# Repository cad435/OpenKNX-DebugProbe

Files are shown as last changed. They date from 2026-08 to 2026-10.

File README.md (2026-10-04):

# OpenKNX DebugProbe

A portable WiFi debugger built on an ESP32-S3 that services an OpenKNX device (RP2040 or
ESP32) through a **single USB-C cable**: **firmware updates** and a **serial console over
TCP**.

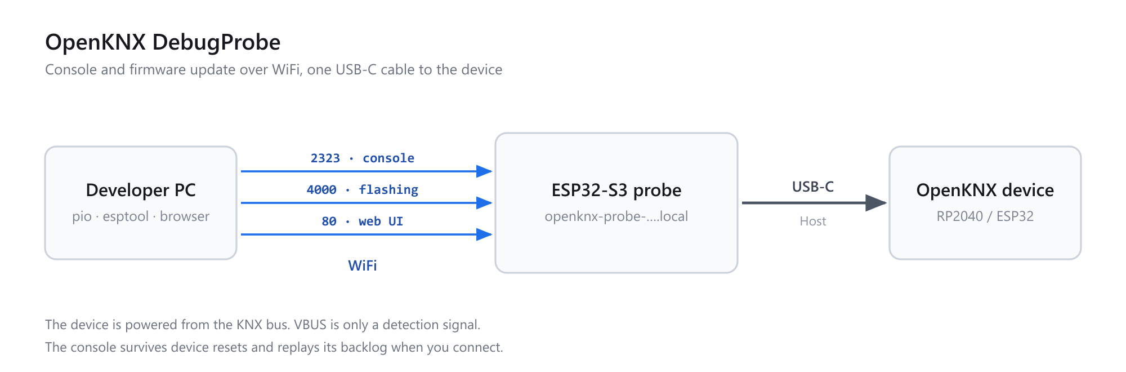
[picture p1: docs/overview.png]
Overview: PC connects to the probe over WiFi, the probe connects to the OpenKNX device with one USB-C cable


## Why

OpenKNX REG1 devices live inside a distribution cabinet. Until now, a firmware update or a
look at the debug console meant carrying a laptop to the cabinet. The probe stays plugged
into the device and is reached over WiFi.

It is built specifically for OpenKNX devices but is **not part of the OpenKNX project** — a
private tool, for now with no affiliation to the OpenKNX group.

## Status

**Working and verified on real hardware.** The whole development cycle runs over WiFi:

| | |
|---|---|
| WiFi setup | captive portal, 3 connection attempts, then a fallback AP |
| Self-update | HTTP OTA with A/B slots and automatic rollback |
| Target detection | RP2040, ESP32, CH32V003, CH34x/CP210x/FTDI — including serial number |
| Console | `socket://…:2323` with a 16 KB backlog, survives target resets |
| Control lines | `rfc2217://…:4000` with baud rate and DTR/RTS |
| Firmware to the target | UF2 over HTTP, fully validated, then written over USB MSC |
| Getting into BOOTSEL | 1200-baud touch, issued by the probe itself — no button press |
| Commands to the target | input line in the browser, selectable line ending, history with ↑/↓ |
| Power saving | the radio dozes while no client is attached to 2323 or 4000 |
| Console in the browser | follow along without a terminal; prompt and ANSI are resolved |
| Ready-made configuration | the `platformio.ini` lines as a copy field and via `/api/snippet` |
| Restarting the target | `/api/reset` and `/api/bootmode`, two buttons in the UI — the probe decides what a given target actually supports and says so |
| Firmware to a CH32V003 | `/api/ch32/flash`, over the rv003usb bootloader's own protocol — no minichlink on the PC |
| Web UI outside the image | in a LittleFS partition, replaceable over WiFi with `/api/fs` |
| Why the probe last started | `reset_reason` tells a brownout from a crash — a target with a high inrush can reset the probe |
| Cell voltage | measured through a divider on the adapter board, reported as `battery` in `/api/status` |

Architecture, hardware and interfaces in detail: **[docs/](docs/)**.

## Modes of operation

- **Normal operation:** `usb_host_cdc_acm` reads the target's console, a TCP server on port
  2323 forwards it to the PC.
- **Flashing:** 1200-baud touch → target reboots into BOOTSEL → `usb_host_msc` writes the
  UF2 as raw 512-byte sectors → reset. `POST /api/flash` issues the touch itself, **after**
  the UF2 has been fully validated; nobody has to press a button on the device. If the mass
  storage device does not appear, one retry follows, then a `409` with a reason — and the
  console is put back to 115200 with DTR/RTS at their idle levels.

The radio saves power when nobody is listening: while a client is attached to 2323 or 4000
it runs with `WIFI_PS_NONE`, otherwise it dozes in `MIN_MODEM`. The console livestream and
flashing are demonstrably unaffected, while the ESP32-S3 runs noticeably cooler when idle.
Only an accepted TCP client gets a vote: HTTP, the web UI and API calls do **not** keep the
radio awake. So an open browser tab costs nothing, a forgotten `pio device monitor` does.
The current state is reported as `radio_awake` in `/api/status` and as the "Funk" row in the
web UI.

The web UI does not only follow the console, it also has a line for **sending commands** to
the target. The line ending is selectable (CR, LF, CRLF, none), because the OpenKNX console
works character by character while other firmware waits for a complete line. ↑/↓ steps
through recently sent commands.

## Supported targets and their USB IDs

**Read the caveat before the table.** On targets with native USB, the VID:PID of the
*running application* is chosen by its firmware, not by the chip. The values below are the
common defaults, not a guarantee. Only the **bootloader** IDs are fixed — they live in the
boot ROM or in a bootloader that is flashed once and then left alone.

That asymmetry is why the probe identifies bootloaders by VID:PID and applications by their
USB class: the first is reliable, the second is not.

| Target | Application (typical) | Bootloader / download | How the probe gets there |
|---|---|---|---|
| RP2040 (arduino-pico) | `2E8A:00C0` | `2E8A:0003` RPI-RP2, mass storage | 1200-baud touch |
| RP2040 (pico-sdk) | `2E8A:000A`, `2E8A:0009` | `2E8A:0003` | 1200-baud touch |
| ESP32-S3 / -C3, native USB | `303A:1001` | **same IDs** — the ROM uses the same USB-Serial-JTAG | DTR/RTS sequence with boot latch |
| ESP32-S2, native USB | `303A:0002`, `303A:1000` | `303A:0002` | DTR/RTS sequence |
| Any board behind a UART bridge | the bridge chip, see below | **unchanged** — the bridge stays visible either way | DTR/RTS on IO0 and EN |
| CH32V003 with rv003usb | firmware's choice (`1209:D003` in the example) | `1209:B003` | HID feature report `0xAB` |

UART bridges, for completeness — these never change between application and bootloader,
because the mode is selected with DTR/RTS rather than by re-enumerating:

`1A86:7523` CH340 · `1A86:5523` CH341 · `1A86:55D3` CH343 · `1A86:55D4` CH9102 ·
`10C4:EA60` CP2102 · `10C4:EA70` CP2105 · `10C4:EA71` CP2108 · `0403:6001` FT232R ·
`0403:6010` FT2232 · `0403:6014` FT232H · `0403:6015` FT230X · `067B:2303` PL2303

### What the probe can do with each

**✅ means verified on real hardware**, not merely implemented. Where a row says
*untested*, the code is there and follows the reference implementation — but nothing has
confirmed it yet, and this table would be worth little if it blurred that line.

| Target | Console | Flash | Restart into the application | Into the bootloader |
|---|---|---|---|---|
| RP2040 (Pico) | ✅ | ✅ UF2 over `/api/flash` | ✅ PICOBOOT, from BOOTSEL only | ✅ 1200-baud touch |
| ESP32-S3 / -C3, native USB | ✅ | ✅ esptool over RFC2217 | ✅ RTS pulse | ✅ DTR/RTS with boot latch |
| CH32V003 (rv003usb bootloader) | — | ✅ `/api/ch32/flash` | ✅ starts the application | ✅ HID feature report `0xAB` |
| ESP32 behind a UART bridge | ✅ | esptool over RFC2217 | *untested* | *untested* |
| Any other HID device | — | — | — | the `0xAB` attempt; a stall is reported as a refusal |

**A running RP2040 cannot be reset over the cable.** Native USB has no reset line, and
PICOBOOT lives only in the boot ROM. Bootmode followed by reset gets there anyway — through
the boot ROM, two clicks, no cable.

**The CH32V003 flasher is written for the V003 specifically.** Sector size and the flash
controller addresses are fixed in the code. Chip *detection* also knows V002/004/005/006/007
and X033, but flashing them is not claimed — a different sector size would have to be taught
first. The scratchpad negotiation and the choice of boot routine already handle the larger
bootloaders, so that part is done.

## Status LED

The module's RGB LED (WS2812 on GPIO48) shows the operating state. Highest urgency wins —
`flashing` beats everything, because pulling the cable there does real damage.

| State | LED | Trigger |
|---|---|---|
| `flashing` | orange, blinking at 320 ms | `POST /api/flash` is writing — **do not unplug** |
| `battery_low` | red, blinking at 1 s | cell nearly empty |
| `no_wifi` | red, pulsing | not connected to WiFi, including portal mode |
| `busy` | solid yellow | a client is attached to 2323 or 4000 |
| `target_ready` | solid green | a target is detected |
| `idle` | green, pulsing | ready, no target attached |

The current mode is reported as `led.mode` in `/api/status`.

Brightness is capped well below maximum. A WS2812 at full white draws around 60 mA, which
matters on battery.

Two more LEDs sit on the SuperMini:

| LED | Meaning |
|---|---|
| blue | the Li-ion charger: on while charging, off once the cell is full, blinking when no cell is connected. |
| red | **shares GPIO48 with the RGB LED.** It lights while the pin is left alone and stays dark as soon as the firmware drives the WS2812 — so on this firmware it is permanently off. |

The shared pin was confirmed on hardware: moving the status LED to another pin brings the
red one back, moving it to GPIO48 turns it off again. It is therefore not a power indicator,
and the RGB LED costs you the red one. If you would rather keep the red LED, point the
status LED at a free pin with `POST /api/led?gpio=N` — the value is stored in NVS.

## Battery

On the adapter board a 1M/1M divider sits behind the battery switch and feeds GPIO5
(ADC1). `/api/status` reports it, and the UI shows a "Zelle" row:

```json
"battery": { "available": true, "level": "normal", "settled": true,
             "mv": 3910, "pin_mv": 1955, "percent": 67, "trim": 1000 }
```

| Field | Meaning |
|---|---|
| `level` | `absent`, `normal`, `low` (< 3.55 V), `critical` (< 3.30 V), or `unknown` while warming up |
| `settled` | false for the first ~25 s after boot, see below |
| `mv` / `pin_mv` | cell voltage and the raw voltage at the divider tap — if the two disagree by anything other than the factor of two, the divider is not what you think it is |
| `percent` | a rough gauge, not a measurement: a generic Li-ion curve over 13 support points, linearly interpolated, with no load compensation — at 30-120 mA the cell sits well below 0.1 C, so the IR drop is small against the spread of the curve itself. It reads 0 % at 3.30 V, the same point as `critical`, because the module's LDO gives up somewhere between 3.0 and 3.5 V; capacity below that is not usable here |

Two things worth knowing:

- **`absent` is the normal case on USB.** The divider is behind the battery switch, so
  with the switch off — or no cell at all — the tap sits at ground. That is not a fault.
- **The first ~25 s after boot report `unknown`.** The tap carries 10 µF against a 500 kΩ
  source impedance, so it charges with a 5 s time constant and reads low until it has
  settled. Without that hold-off the probe would announce an empty cell at every start.

If the reading disagrees with a multimeter, trim it once: measure at the cell and post
the value.

```bash
curl -X POST "http://openknx-probe-xxxx.local/api/battery/calibrate?mv=3870"
```

The factor is stored in NVS and applied from then on. 1 % resistors alone allow 2 % on the
divider ratio, and the ADC characteristic adds to that — around 100 mV at 3.8 V, enough to
move the low-battery warning by half an hour. Corrections beyond 25 % are rejected.

## Enclosure

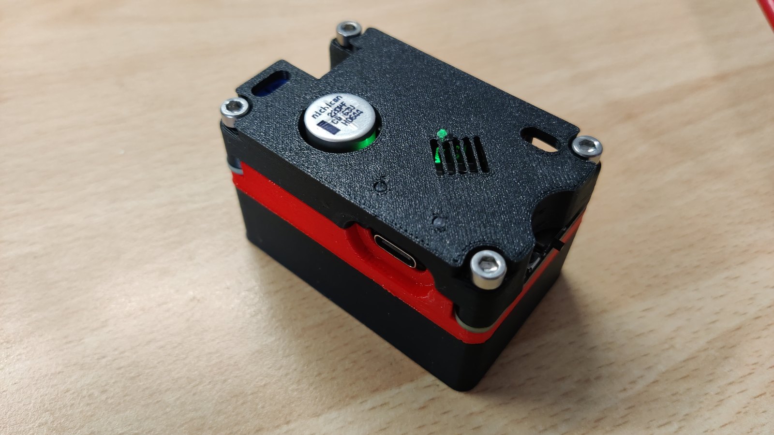
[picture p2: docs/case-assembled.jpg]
The assembled probe in its printed enclosure: black lid, red body, black battery compartment, four socket-head screws in the corners


A printable enclosure is included as a Fusion 360 archive:
[`hardware/OpenKNXDebugProbe.f3z`](hardware/OpenKNXDebugProbe.f3z). It is made of three
parts:

| Part | Purpose |
|---|---|
| **Top** | lid with the openings for USB-C, the status LED and the electrolytic capacitor |
| **Bottom** | the counterpart; the PCB is clamped between top and bottom |
| **Battery compartment** | optional, goes underneath and holds the cell |

Assembly needs **four M3×20 screws**. They go in from the top and thread straight into the
plastic — no heat-set inserts, no captive nuts. The board is not screwed down itself; it is
held by being clamped between the top and bottom parts.

**Without a battery** you can leave the battery compartment off and counter the four screws
with M3 nuts underneath instead.

## PlatformIO integration

No extra hardware is needed on the PC side — a few lines in the target project's
`platformio.ini` are enough. The probe hands them out itself, since it knows its own name
and what is plugged in:

```powershell
curl.exe http://openknx-probe-xxxx.local/api/snippet
```

The web UI shows the same lines in two copy fields as soon as a target is detected. If you
would rather write them yourself:

```ini
; RP2040 target (UF2 over HTTP)
monitor_port    = socket://openknx-probe-xxxx.local:2323
upload_protocol = custom
upload_command  = curl --fail-with-body --data-binary "@$BUILD_DIR/${PROGNAME}.uf2" http://openknx-probe-xxxx.local/api/flash

; ESP32 target (esptool over RFC2217)
upload_port     = rfc2217://openknx-probe-xxxx.local:4000
upload_speed    = 460800
```

Fully commented in [tools/platformio-snippet.ini](tools/platformio-snippet.ini).

## Build and flash

```powershell
cd firmware
pio run              # build
pio run -t upload    # flash (the port is detected automatically)
```

PlatformIO with `framework = espidf`, platform espressif32 54.3.21 (ESP-IDF 5.4.2). A
separate ESP-IDF installation is not required.

## First-time setup

1. Flash the firmware. The probe finds no credentials and opens an open WiFi network
   named after itself, e.g. `OpenKNX-Probe-A1B2`.
2. Connect to it — the captive portal opens by itself, otherwise `http://192.168.4.1/`.
3. Pick a network and enter the password. The device name is not configurable: it is
   always `OpenKNX-Probe-<last two MAC bytes>`, so it is unique per board and matches
   the setup network you just joined.
4. After the restart the probe is reachable at `http://<name>.local/`.

The probe remembers **one** network. Entering another one replaces it. Also note that the
fallback AP only ever opens during startup: once the probe has an address, a link that
gets weak or drops is retried indefinitely and never falls back to the portal. To reach
the portal on purpose, restart the probe while its network is out of reach.

## Self-update

From the browser via the start page, or:

```powershell
curl.exe --fail-with-body --data-binary "@firmware/.pio/build/probe/firmware.bin" `
         http://openknx-probe-xxxx.local/api/update
```

A foreign or damaged image is rejected with HTTP 400 before anything is written. If a new
image does not boot cleanly, the bootloader falls back to the previous one automatically.

## Security

The probe has **no authentication**. Anyone who can reach it on the network can, with no
further hurdle,

- write firmware into the attached target (`POST /api/flash`),
- overwrite the probe itself over OTA (`POST /api/update`),
- send commands to the target's console (`POST /api/console`),
- push the target into BOOTSEL (`POST /api/bootsel`), and
- erase the stored WiFi credentials (`POST /api/wifi/forget`).

The setup AP is **open** as well, without WPA — during first-time setup anyone within radio
range can set the credentials.

This is deliberate: the probe is a tool for the bench and your own development network,
where turnaround time matters and a login on every flash would only get in the way. But it
follows where it does **not** belong: not on a guest network, not on a network with
strangers on it, and never behind a port forward or a reverse proxy exposed to the
internet. If it stays in the cabinet permanently, it belongs on the same trusted network as
the devices it is allowed to flash — because that is exactly what anyone who reaches it can
do.

## Documentation

| File | Contents |
|---|---|
| [docs/architecture.md](docs/architecture.md) | state machine, tasks, core split |
| [hardware/](hardware/) | probe module, power supply, battery, VBUS |
| [docs/protocol.md](docs/protocol.md) | HTTP API and TCP serial interface |

`docs/architecture.md` is currently German only.

## License

[GNU General Public License v3.0 or later](LICENSE) (`GPL-3.0-or-later`).

Espressif's USB host and mDNS components, which the build pulls in through the Component
Manager, are Apache-2.0 licensed and are not part of this repository.

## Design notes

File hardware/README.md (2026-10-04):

# Hardware

Schematic as PDF: [OpenKNX-DebugProbe_V0.2-Schematic.PDF](OpenKNX-DebugProbe_V0.2-Schematic.PDF)

Printable enclosure: [OpenKNXDebugProbe.f3z](OpenKNXDebugProbe.f3z) (Fusion 360 archive).
Three parts, four M3×20 screws — see [Enclosure](../README.md#enclosure) in the main README.

## Probe module

The controller is an **ESP32-S3 SuperMini** (FH4R2 variant) — **not an ESP32-S3 Zero!**
The USB-C connector towards the target is the module's own — there is none on the adapter board.

The module's 4 MB of flash are the tightest constraint: two OTA slots of 1.875 MB each,
leaving no room for a UF2 staging partition. The target's UF2 is therefore buffered in
PSRAM.

## Power supply

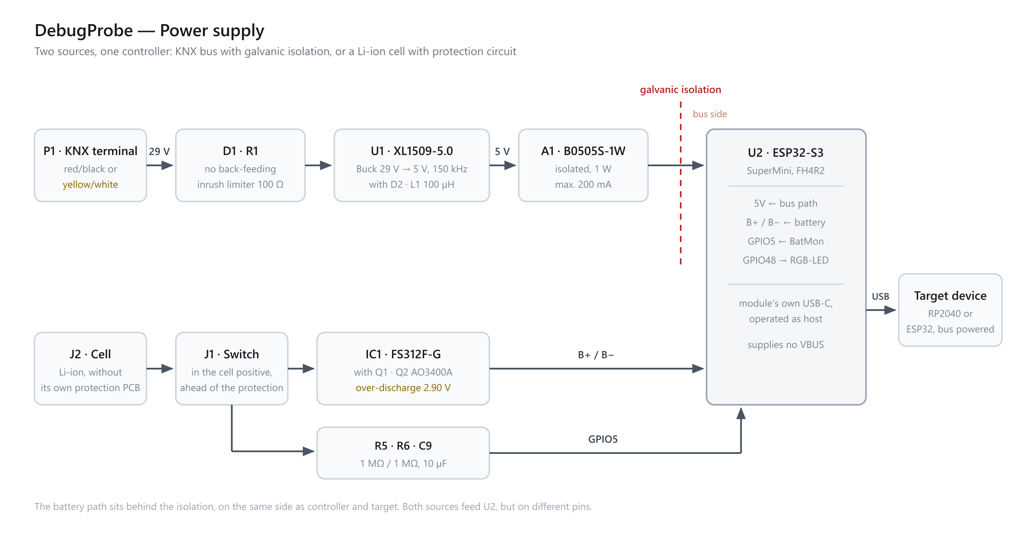
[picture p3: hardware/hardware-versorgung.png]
Power supply


`D1` sits directly behind KNX+ and prevents back-feeding: KNX transmits by briefly pulling
the bus LOW, and no charge may flow back into the bus from the input capacitor. That is the
reason for it — not reverse-polarity protection.

`A1` breaks the ground loop between the bus supply and the target — either the red/black or
the yellow/white terminal pair can be used, or any other supply from 5 V to 30 V.

## Battery (optional)

The battery is optional; without it the probe runs from the bus supply. Charging is handled
by the ESP32-S3 SuperMini's charger. The protection circuit against over-discharge, however,
sits on this probe board, because the cell does not bring its own.

**Open the switch when the probe is not in use.** It disconnects the cell completely, so
that neither the module nor the protection circuit draws current.

The cell voltage reaches an ADC input through a divider. Its 10 µF give a time constant of
5 s — so the first usable reading is about 30 s after switch-on.

## VBUS

All OpenKNX devices are KNX bus powered. **The probe supplies no VBUS**, and an RP2040/ESP32
target with native USB still enumerates: it asserts its D+ pull-up as soon as the board has
power.

On the bench it is different — a bare RP2040 devkit is USB powered and draws real current
from VBUS.

## Proof-of-Concept prototype

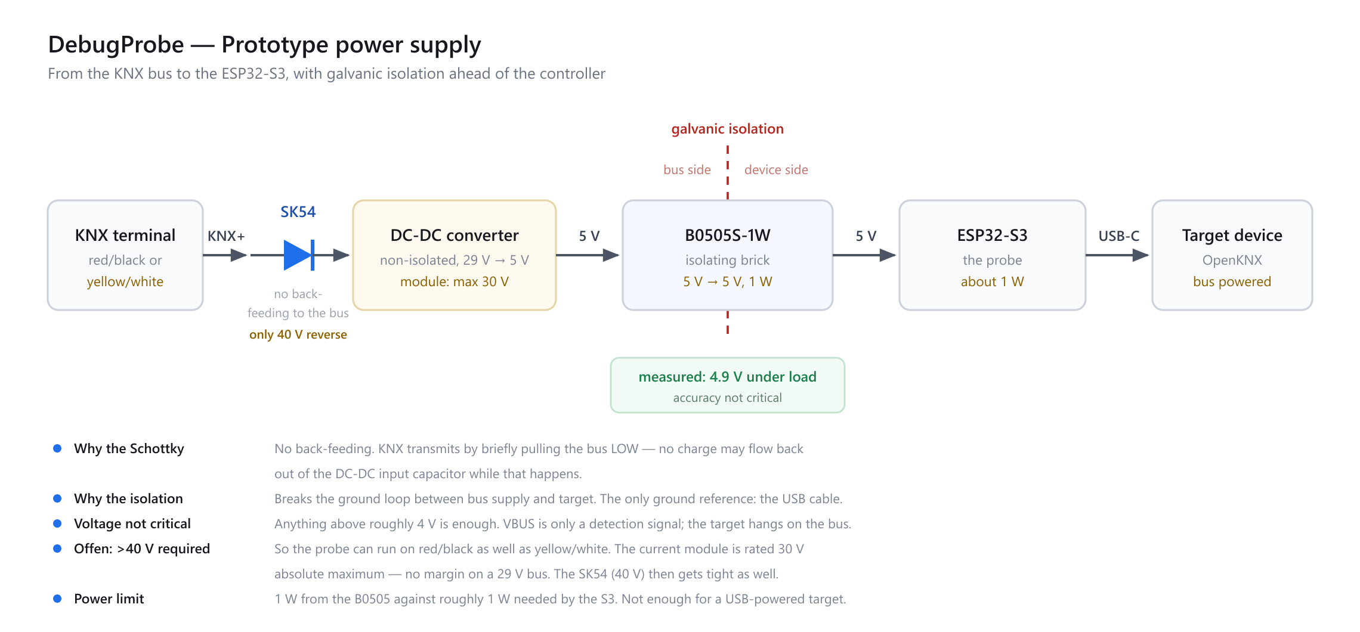
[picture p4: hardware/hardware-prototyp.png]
Power supply chain of the prototype


The prototype differs from the schematic: an **MP1584** module serves as the buck converter
instead of `U1`, and the battery branch is missing. The isolated converter and the
controller are the same.

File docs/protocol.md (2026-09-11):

# Interfaces

Legend: **[live]** = implemented and verified on real hardware.

For uploads the file content is always transferred as the **raw request body**
(`--data-binary`), never as multipart. That saves a multipart parser on the probe and works
equally well from a browser (`fetch(url, {method:"POST", body: file})`) and from `curl`.

## Discovery

mDNS hostname from the portal, default `openknx-probe-<mac>` (e.g.
`openknx-probe-xxxx.local`). Service `_http._tcp`, instance name
"OpenKNX DebugProbe". **[live]**

## TCP — the target's serial console **[live]**

| Port | Protocol | Used for |
|---|---|---|
| 2323 | raw, transparent | monitor, terminal |
| 4000 | RFC2217 (Telnet + COM-PORT-OPTION) | anything needing baud rate and DTR/RTS |

Both share the same 16 KB backlog and may be connected at the same time.

Behaviour on **2323**:

- On connect you first get a status line `[probe] …`, then the backlog — including the boot
  messages that appeared before you connected.
- If the target disappears (reset or flash), **the TCP connection stays up**; the state
  change appears as a `[probe]` line in the stream.
- One client at a time.

Behaviour on **4000**:

- Starts at the current end of the buffer, not at its beginning — a flashing tool should not
  find old console output in its protocol stream.
- Supported subnegotiations: `SET_BAUDRATE`, `SET_DATASIZE`, `SET_PARITY`, `SET_STOPSIZE`,
  `SET_CONTROL` (DTR/RTS), `SET_LINESTATE_MASK`, `SET_MODEMSTATE_MASK`, `PURGE_DATA`. BREAK
  is not passed through yet.
- 0xFF in the payload stream is doubled in both directions.

PC side:

```
monitor_port = socket://openknx-probe-xxxx.local:2323
esptool --port rfc2217://openknx-probe-xxxx.local:4000 write_flash ...
```

## HTTP API

### `GET /` **[live]**

Status and update page. In portal mode the provisioning form instead.

### `GET /api/status` **[live]**

```json
{
  "name": "openknx-probe-xxxx",
  "version": "1",
  "build": "Aug 19 2026 00:23:28",
  "partition": "ota_1",
  "pending_verify": false,
  "wifi": "connected",
  "ssid": "<SSID>",
  "rssi": -43,
  "ip": "<IP>",
  "uptime_s": 47,
  "heap_free": 2230844,
  "target":  { "state": "connected", "description": "…", "vid": "0x2E8A", … },
  "console": { "port": 2323, "client": "…", "rx": 12345, "rfc2217_port": 4000, … },
  "snippet": { "comment": "…", "monitor": "…", "upload": "…" }
}
```

`wifi`: `idle` | `connecting` | `connected` | `portal`
`pending_verify`: `true` while a freshly flashed image is still on probation.
`target` and `console` are absent while the USB host has not been started; the fields inside
`target` only exist in state `connected`.

Four fields inside `target` are the exception — they exist in every state, because the web UI
needs them to decide whether the restart buttons do anything at all:

| field | meaning |
|---|---|
| `can_reset` | a restart into the target's own application is possible |
| `reset_how` | the method used, or — when `can_reset` is `false` — the reason |
| `can_bootmode` | the target can be halted in its bootloader |
| `bootmode_how` | same, for the bootloader |

Both `*_how` fields are plain German text meant to be shown to a human. Do not parse them;
they are documentation, not a protocol.

One call is enough for the whole web UI page — it polls this single route.

### `POST /api/update` **[live]** — firmware of the **probe**

Raw body with the ESP32 application image. Writes into the inactive OTA slot and reboots
afterwards.

```powershell
curl.exe --fail-with-body --data-binary "@firmware/.pio/build/probe/firmware.bin" http://…/api/update
```

| Status | Meaning |
|---|---|
| 200 | written, reboot follows (`{"status":"ok","partition":"ota_1"}`) |
| 400 | not a valid ESP32 image, wrong project, or bad checksum — **nothing was written** |
| 409 | an update is already running |
| 413 | image larger than the OTA slot |

Checked before the first write: image magic `0xE9`, a present `esp_app_desc_t`, and a
matching project name. In particular this keeps a UF2 that was actually meant for the target
from ending up in the ESP32 by accident.

### `POST /api/fs` **[live]** — the web UI (filesystem image)

Writes the LittleFS image into the `storage` partition. The counterpart of `/api/update`:
that one carries the firmware, this one the interface. Body is the raw `littlefs.bin`.

```
curl.exe --fail-with-body --data-binary "@firmware/.pio/build/probe/littlefs.bin" http://openknx-probe-xxxx.local/api/fs
```

```json
{"status":"ok","written":196608,"total_kb":180,"used_kb":28,"index":true}
```

`index` is `false` when the image contains no `index.html` — the upload worked, but the probe
will still serve the built-in emergency page.

| code | meaning |
|---|---|
| 400 | empty body, too short, or not a LittleFS image |
| 409 | an upload is already running |
| 413 | image larger than the partition |
| 500 | erase, write, or remount failed |

**Why this endpoint exists at all.** Without it, every change to the interface needs a serial
`pio run -t uploadfs`. On a probe whose USB-C port is occupied by the target under test, that
means unplugging cables — the exact thing this project exists to abolish.

**The image is validated before anything is erased.** LittleFS carries the string `littlefs`
at offset 8 of its first block; that is checked the same way `/api/update` checks the ESP32
image magic. A `firmware.bin` sent here is refused rather than silently turned into an empty
interface.

**An aborted upload is not fatal.** The filesystem is unmounted for the duration, so a broken
transfer leaves the partition incomplete — the probe keeps running, serves the emergency page,
and this endpoint stays reachable. A second attempt repairs it. What cannot be repaired this
way is a probe that no longer joins the network; that is what the serial path is for.

### `GET /api/scan` **[live]**

List of visible WiFi networks, sortable by signal strength:
`[{"ssid":"…","rssi":-43,"open":false}, …]` (max. 20 entries).

### `POST /api/wifi/connect` **[live]**

`application/x-www-form-urlencoded` with `ssid`, `pass`, optionally `name` (device name).
Stores to NVS and reboots. Used by the captive portal.

### `POST /api/wifi/forget` **[live]**

Erases the stored credentials and reboots into the portal.

---

### `POST /api/flash` **[live]** — firmware of the **target**

Raw body with the UF2. It is buffered in PSRAM, **fully validated**, and only then written
as raw 512-byte sectors. Magics, the block chain, `numBlocks` and the family ID are checked;
if anything fails, not a single sector reaches the target.

If the target is still running its application, the endpoint pushes it into BOOTSEL
**itself** with a 1200-baud touch — only after validation, so a broken file cannot tear the
target out of its application. Nobody has to press a button. If the target already sits in
BOOTSEL, nothing is touched.

```powershell
curl.exe --fail-with-body --data-binary "@firmware.uf2" http://openknx-probe-xxxx.local/api/flash
```

| Status | Meaning |
|---|---|
| 200 | written (`{"blocks":…,"written":…}`), the target reboots |
| 400 | invalid UF2 — **nothing** on the target was changed |
| 409 | touch attempted, but BOOTSEL not reached (reason in `error`) |
| 413 | no memory for the file |
| 502 | write error midway through |

Every rejection names its reason in `{"error":…}`. Checks run in the order in which the
causes actually occur: **the magic at the start of the file first**, only then the size. The
other way round, the most common case — an accidentally sent `firmware.bin` — would get
"not a multiple of 512", and that points in the wrong direction.

```json
{"error":"kein UF2-Magic (0x0A324655) am Dateianfang, sondern 0x20003FFC, 572636 Byte
          empfangen - das sieht nach einer .bin aus. In der platformio.ini
          \"@$BUILD_DIR/${PROGNAME}.uf2\" statt \"@$SOURCE\" verwenden."}
```

The probe decides this after the first 512 bytes, **before** it requests memory for the
file. For the text to also show up in the PlatformIO log, the snippet needs
`--fail-with-body` instead of `-f`: with `-f`, curl swallows the body and all that remains
is `curl: (22)`.

`?validate_only=1` checks the file without writing and returns
`{"blocks":…,"payload_bytes":…,"first_address":…,"family":…,"status":"valid"}`.

The endpoint establishes BOOTSEL mode itself (1200-baud touch, see above) — **as long as the
target's firmware still enumerates**. Only when it no longer does, somebody has to step in:
BOOTSEL and RUN are accessible from the front panel, and the probe detects the state change
by itself. A power cycle over VBUS explicitly does not help there, because all OpenKNX
devices are KNX bus powered — see [hardware/](../hardware/).

### `GET /api/console?cursor=N` **[live]**

The target console's backlog for the browser. `cursor` is an **absolute** position in the
stream, not a ring-buffer index; without the parameter you get the entire available buffer.

```json
{ "cursor": 20480, "skipped": 0, "more": false, "data": "…" }
```

| Field | Meaning |
|---|---|
| `cursor` | use this value for the next request |
| `skipped` | this many bytes were overwritten before they were fetched |
| `more` | there is more waiting — fetch again immediately, without waiting |
| `data` | the raw bytes, JSON-escaped (control characters as `\u00XX`) |

At most 4 KB per response, so that a single response burdens neither the heap nor the
browser; hence the `more` flag.

The raw bytes stay raw: CR, LF and ANSI sequences pass through unchanged. The OpenKNX
console rewrites its prompt after every log line and erases it next time with `ESC[2K` — the
web UI runs a small line state machine for that (CR only moves the cursor, it erases
nothing).

`/api/status` carries `radio_awake` alongside: `true` while a client is attached to 2323 or
4000 and the radio therefore runs with `WIFI_PS_NONE`, otherwise `false`
(`WIFI_PS_MIN_MODEM`). HTTP itself does **not** keep the radio awake.

### `POST /api/console` **[live]** — command to the target

The body is the raw text **without** a line ending; `?eol=cr|lf|crlf|none` decides what gets
appended (default `cr`). Response `{"status":"sent","bytes":N}`.

Why it is selectable: the OpenKNX console works character by character — every keystroke is
processed and echoed immediately — while other firmware waits for a complete line. A
hard-coded line ending would break one case in order to serve the other. An empty body with
`eol=cr` sends just the line ending, which makes the prompt redraw.

The bytes take the same path as those of a TCP client on port 2323, so they are counted in
`bytesToTarget()` and appear in `/api/status` under `console.tx`. Anything longer than
512 bytes is rejected with `413` — this endpoint is for typed commands, not for files.

| Status | Meaning |
|---|---|
| 200 | written |
| 400 | unknown `eol`, or nothing to send |
| 409 | no serial session to the target is open |
| 413 | command longer than 512 bytes |
| 502 | writing to the target failed |

Verified on hardware against an OpenKNX fan actuator: `h` returns the complete help,
`uptime` the running time — both entered through the web console.

### `POST /api/reset` **[live]** — restart the target

Restarts the attached target into its own application. No body.

```json
{"status":"reset","method":"RTS-Puls auf EN (esptool-Hard-Reset)","msc_ready":false}
```

`method` names what the probe actually did, which differs per target — there is no single
mechanism that restarts every device over USB:

| target | reset into the application |
|---|---|
| UART bridge (CH34x / CP210x / FTDI) | RTS pulse on EN, the esptool hard reset |
| Espressif with native USB | RTS pulse through the USB-Serial-JTAG, after clearing the boot latch |
| RP2040 (CDC) | **not directly** — but bootmode followed by reset gets there via the boot ROM |
| RP2040 in BOOTSEL | PICOBOOT reboot over the boot ROM's vendor interface |

**A running RP2040 with native USB cannot be reset directly.** DTR and RTS end up in the
target's firmware, not at its RUN pin, and there is no line in between. The endpoint says so
instead of pretending: `409` with the reason in `error`. Ask `/api/status` beforehand —
`can_reset` carries the same answer without touching anything.

**It still works remotely, in two steps:** `POST /api/bootmode`, then `POST /api/reset`. The
first uses the 1200-baud touch, the second the boot ROM's PICOBOOT interface — the same one
`picotool reboot` drives. The route goes through the boot ROM, but it needs no cable. Once a
target sits in BOOTSEL, `/api/status` reports `picoboot: true` and `can_reset: true`.

### `POST /api/bootmode` **[live]** — halt the target in its bootloader

The counterpart. No body.

```json
{"status":"bootmode","method":"1200-Baud-Touch","msc_ready":true,"msc_kb":131071}
```

| target | into the bootloader |
|---|---|
| UART bridge | DTR/RTS sequence on IO0 and EN, the esptool bootloader reset |
| Espressif with native USB | DTR/RTS sequence through the USB-Serial-JTAG, setting the boot latch |
| RP2040 (CDC) | 1200-baud touch — the same thing `/api/flash` does internally |
| RP2040 in BOOTSEL | nothing to do, `method` says so |

Useful for testing the touch without overwriting the target's firmware, and as a button in
the web UI. On failure, `409` with the same `error` text as `/api/flash`.

An RP2040 returns to its application through a reset (RUN button or power cycle) or through
the next `POST /api/flash`. The flash contents are untouched by the touch.

**Both control-line sequences set DTR and RTS in a single USB control transfer.** The
intermediate state that pyserial produces over RFC2217 — one line at a time, roughly 50 ms
apart — never occurs here. That state is exactly what the auto-reset circuit on ESP32 boards
is built to ignore.

**On chips with a native USB-Serial-JTAG the same interlock lives inside the chip**, which
is why download mode is not selected by a pin level but by a latch: a phase with DTR
asserted is remembered, and the next reset then boots into download mode. The probe clears
that latch before a plain restart and sets it before a bootloader entry. Verified on an
ESP32-S3: `/api/reset` yields `boot:0x2b (SPI_FAST_FLASH_BOOT)`, `/api/bootmode` yields
`boot:0x23 (DOWNLOAD(USB/UART0))`.

### `POST /api/bootsel` **[live]** — deprecated alias

The old name of `/api/bootmode`, from when the only supported target was an RP2040. Same
handler, same response — including `status:"bootmode"`. New code should use `/api/bootmode`.

### `GET /api/snippet` **[live]**

The ready-made `platformio.ini` lines for the currently attached target, as `text/plain`.
Meant for scripts and AI agents: one call is enough to get the right configuration without
knowing the ports and baud rates yourself.

```
; OpenKNX DebugProbe - openknx-probe-xxxx.local
; Ziel: Raspberry Pi Pico (USB-CDC) (2E8A:000A)
monitor_port  = socket://openknx-probe-xxxx.local:2323
monitor_speed = 115200
upload_protocol = custom
upload_command  = curl --fail-with-body --data-binary "@$BUILD_DIR/${PROGNAME}.uf2" http://openknx-probe-xxxx.local/api/flash
```

Which upload path appears depends on the detected target: **VID `0x2E8A`** (RP2040) gets the
UF2 path over `/api/flash`, everything else `upload_port = rfc2217://…:4000` with
`upload_speed = 460800`. With no target attached only the two console lines remain, with
`; Ziel: kein Zielgeraet angesteckt` as the comment.

The same strings appear under `snippet` in `/api/status` and fill the two copy fields in the
web UI. They are built **in the firmware** (`buildSnippet()` in `main.cpp`) — that way the
endpoint and the display cannot drift apart when a port changes.

## PlatformIO integration in the target project **[live]**

```ini
[env:openknx_remote]
monitor_port    = socket://openknx-probe-xxxx.local:2323
upload_protocol = custom
upload_command  = curl --fail-with-body --data-binary "@$BUILD_DIR/${PROGNAME}.uf2" http://openknx-probe-xxxx.local/api/flash
```

Fully commented in `tools/platformio-snippet.ini`, which also has the `rfc2217://` variant
for ESP32 targets.

More convenient than copying it by hand is fetching both — the probe knows its own name and
the attached target:

```powershell
curl.exe http://openknx-probe-xxxx.local/api/snippet
```

The web UI shows the same lines in two copy fields.

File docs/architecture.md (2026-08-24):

# Architektur

## Überblick

```
   PC                          WLAN                    Schaltschrank
+---------+                                   +-------------------------+
| pio     |--- TCP  :2323 ------------------->| serial_bridge           |
| monitor |                                   |        ^                |
|         |                                   |        v                |
| curl /  |--- HTTP :80  ------------------->| web_api -> uf2_flasher  |
| Browser |                                   |        ^                |
+---------+                                   |        v                |
                                              | usb_target (USB Host)   |
                                              | target_power (VBUS)     |
                                              +-----------+-------------+
                                                          | USB-C
                                                          v
                                                 OpenKNX RP2040
```

## Task- und Core-Aufteilung

| Task | Core | Aufgabe |
|---|---|---|
| `usb_host_lib` (IDF) | 1 | USB-Host-Eventschleife, muss möglichst jitterarm laufen |
| `usb_target` | 1 | Zustandsmaschine, CDC-Transfers, MSC-Transfers |
| `serial_bridge` | 0 | TCP-Server, Ringpuffer |
| `web_api` (httpd) | 0 | HTTP-Server, Upload-Streaming |
| WiFi/lwIP (IDF) | 0 | Funk |

Die strikte Trennung USB (Core 1) / Netz (Core 0) ist der Hauptgrund für den ESP32-S3:
auf einem Einkern-S2 konkurrieren USB-Host-Stack und WiFi um dieselbe CPU, und genau das
erzeugt sporadische Aussetzer, die sich später kaum reproduzieren lassen.

## Zustandsmaschine `usb_target`

```
        +-----------------+
        |  NO_TARGET      |  kein Gerät / VBUS aus
        +--------+--------+
                 | Device connect
                 v
        +-----------------+
        |  ENUMERATING    |
        +--+-----------+--+
           |           |
   CDC-ACM |           | MSC (VID 2e8a / PID 0003)
           v           v
   +-------------+  +-------------+
   |  CONSOLE    |  | BOOTSEL_MSC |
   +------+------+  +------+------+
          |                |
   flash  | 1200-Baud-     | UF2 validiert
   request| Touch          v
          |         +-------------+
          +-------->|  FLASHING   |
                    +------+------+
                           | letzter Block geschrieben
                           v
                    +-------------+
                    | POST_FLASH  |  Ziel rebootet selbst
                    +------+------+
                           | CDC wieder da
                           v
                        CONSOLE
```

Fehlerpfade:

- `ENUMERATING` -> Timeout (5 s) -> `NO_TARGET`, VBUS kurz aus/ein, ein Retry.
- Touch abgesetzt, aber kein MSC innerhalb 5 s -> ein Retry, danach `ERROR`. Am Endpunkt
  ist das ein `409` mit Begründung; vorher werden Baudrate und Steuerleitungen in den
  Konsolen-Ruhezustand zurückgestellt, damit ein gescheiterter Touch das Ziel nicht mit
  1200 Baud und abgefallenem DTR zurücklässt. Danach bleibt der manuelle Griff ans Gerät:
  BOOTSEL und RUN sitzen an der Frontblende.
- `POST_FLASH` ohne CDC innerhalb 15 s -> `ERROR` mit Hinweis "Firmware startet nicht".

## Flash-Ablauf im Detail

1. **Upload.** `POST /api/flash` puffert die UF2 im **PSRAM**: im 4-MB-Flash der Probe
   wäre für eine ~1,4-MB-UF2 kein Platz, die 2 MB PSRAM reichen dafür. Der Puffer
   überlebt keinen Reboot, ein Re-Flash braucht also einen neuen Upload. Beurteilt wird
   schon nach den ersten 512 Byte, **bevor** Speicher angefordert wird — siehe
   `Uf2Flasher::checkPrologue()`.
2. **Validierung.** Erst vollständig prüfen, dann handeln: Magic Start `0x0A324655` /
   `0x9E5D5157`, Magic End `0x0AB16F30`, Family-ID `0xe48bff56` (RP2040), `numBlocks`
   konsistent, Blockkette lückenlos. Schlägt das fehl, wird der Touch **nie** ausgelöst.
3. **Touch.** CDC-Line-Coding auf 1200 Baud setzen, DTR aktivieren, kurz halten, wieder
   fallen lassen — genau die Bussequenz, die ein Öffnen und Schließen des Ports am PC
   erzeugt (das meint PlatformIO mit „Forcing reset using 1200bps open/close"). Das Ziel
   rebootet nach BOOTSEL. Implementiert in `UsbTarget::enterBootsel()`; die 1200 werden
   **nicht** in `m_baudRate` übernommen, damit die Konsole nach dem Flashen wieder mit
   115200 aufgesetzt wird. Ein Ziel, das schon im BOOTSEL steht, wird nicht angefasst.
4. **Schreiben.** Das Ziel meldet sich als MSC mit VID `0x2e8a` / PID `0x0003`.
   Die UF2-Blöcke werden als **rohe 512-Byte-Sektoren** per SCSI `WRITE(10)` geschrieben —
   das Boot-ROM durchsucht eingehende Sektoren nach dem UF2-Magic und ignoriert die
   FAT-Struktur. Damit entfällt FatFs auf der Probe komplett.
   *(Am Gerät bestätigt: 296 Blöcke in 1,7 s, Ziel rebootet und meldet sich zurück.)*
5. **Selbst-Reset.** Sobald das Boot-ROM alle Blöcke hat, rebootet es sofort. Der letzte
   Schreibzugriff bzw. das folgende `TEST UNIT READY` **schlägt planmäßig fehl** — das ist
   Erfolg, kein Fehler. Diese Stelle ist die häufigste Fehlerquelle in eigenen Flashern.

## Serieller Pfad

- `usb_host_cdc_acm` liest kontinuierlich, schreibt in einen Ringpuffer (Vorschlag 16 KB).
- Der TCP-Server gibt bei Verbindungsaufbau den Puffer-Inhalt aus, damit Boot-Meldungen
  nicht verloren gehen, die vor dem Verbinden aufliefen.
- Kein Client verbunden: weiterlesen und puffern, nicht blockieren.
- Ziel verschwindet (Reset/Flash): TCP-Verbindung **offen halten**, optional eine
  Statuszeile einblenden, bei Rückkehr nahtlos weiterliefern.
- Optional RFC2217 auf zweitem Port, wenn Baudraten-Umschaltung vom PC gebraucht wird.

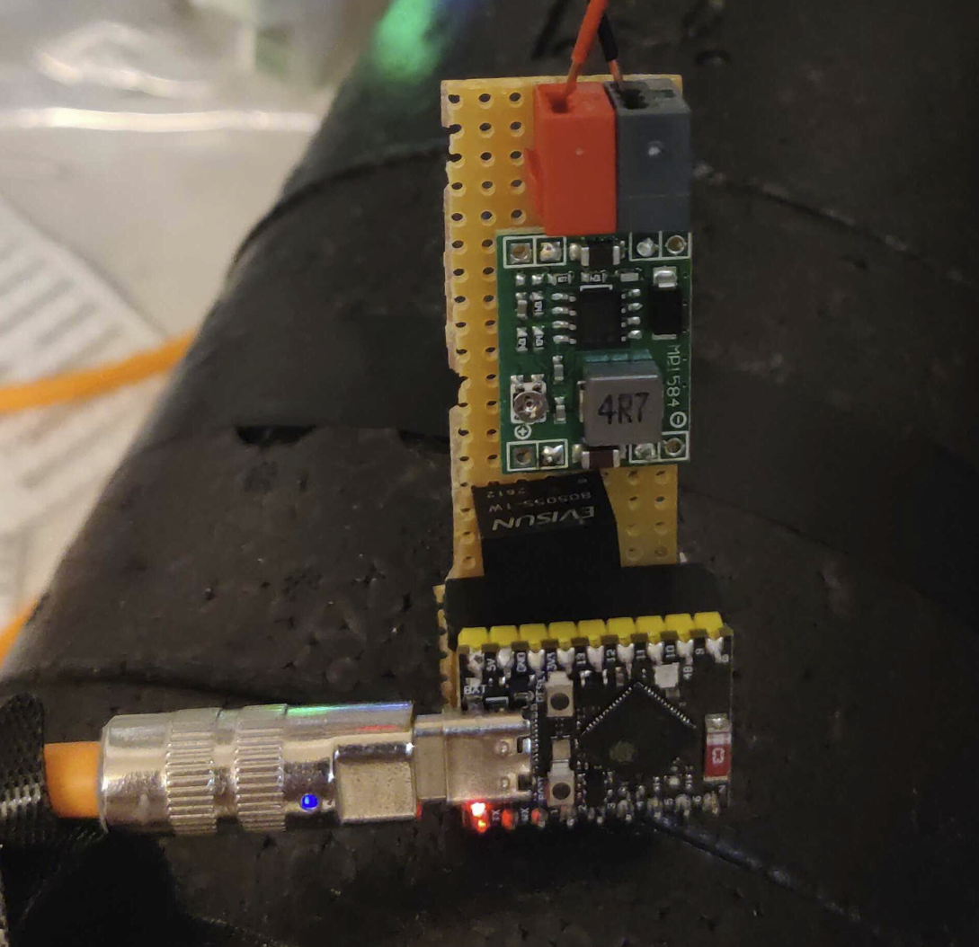
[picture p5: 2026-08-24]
hardware/Prototype_Concept.png

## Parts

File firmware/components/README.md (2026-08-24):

# Components

| Component | Status | Verantwortung |
|---|---|---|
| `settings` | **implementiert** | RAII-Wrapper um einen NVS-Namespace |
| `web_api` | **implementiert** | Der eine HTTP-Server der Probe; alle Features registrieren ihre Routen hier |
| `net_wifi` | **implementiert** | WLAN-Verbindung, Captive-Portal-Provisioning, mDNS, dynamisches Stromsparen |
| `ota_update` | **implementiert** | Selbst-Update über HTTP mit A/B-Slots und Rollback |
| `usb_target` | **implementiert** | USB-Host: Enumeration, Identifikation, CDC/VCP-Sitzung, MSC, 1200-Baud-Touch nach BOOTSEL |
| `serial_bridge` | **implementiert** | TCP 2323 ⟷ CDC des Ziels mit Ringpuffer, dazu RFC2217 auf 4000 |
| `uf2_flasher` | **implementiert** | UF2 vollständig validieren, dann als rohe 512-Byte-Sektoren schreiben |
| `target_power` | Stub | VBUS-Load-Switch, Strommessung — optional, siehe `hardware/README.md` |

Geschrieben wird **ohne Dateisystem**: das RP2040-Boot-ROM durchsucht jeden eingehenden
Sektor nach dem UF2-Magic und ignoriert die FAT-Struktur des `RPI-RP2`-Volumes. FatFs auf
der Probe entfällt damit komplett.

`target_power` ist eine leere ESP-IDF-Component (`idf_component_register()` ohne Quellen),
damit der Build grün bleibt, solange sie nicht gebraucht wird. Bei busgespeisten Zielen ist
der Load-Switch nur noch optional — ein Power-Cycle über VBUS erzwingt dort ohnehin keinen
Reset, sondern nur ein Re-Enumerieren.

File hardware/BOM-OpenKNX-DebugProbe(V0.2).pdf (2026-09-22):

Comment | Description | Designator | Footprint | Quantity
B0505S-1W | | A1 | B05_S-1WR3 | 1
10uF | Capacitor | C1, C9 | C0603 | 2
47uF/10V | Capacitor | C2, C5, C6, C7 | C1206 | 4
220uF/63V | Polarized Capacitor (Axial) | C3 | CAP-SMD_BD12.5-L13.0-W13.0-LS14.4-FD | 1
100nF | Capacitor | C4, C8, C11 | C0603 | 3
SS210 | Diode | D1, D2 | DO-214 | 2
FS312F-G | Battery Protection IC | IC1 | SOT23-6 | 1
12C02 | Switch_THT | J1 | SW-SMD_12C02 | 1
Terminalblock X2 | | J2 | Terminalblock_X2_3.5 mm | 1
Terminalblock X2 | | J3 | Terminalblock_X2_5m m | 1
Tactile Switch | Tactile Switch | J4 | TS-1088-AR02016 | 1
100uH/500mA | Inductor | L1 | 5x5mm | 1
KNX | Wago 243-211 / KNX Klemme Schwarz/Rot | P1 | Wago 243-211 / KNX B/ R | 1
AO3400A | 30V N-Channel MOSFET | Q1, Q2 | SOT23 Normal | 2
100 | Resistor | R1 | R2512 | 1
1k | Resistor | R2, R7 | R0603 | 2
0 | Resistor | R3 | R0603 | 1
1M | Resistor | R5, R6 | R1206 | 2
100 | Resistor | R8 | R0603 | 1
XL1509-5.0E1 | XL1509-5.0E1 | U1 | SOP8 | 1
ESP32-S3 Supermini | ESP32-S3 SuperMini (nologo.tech). 18 castellated edge pins, 20 bottom-side test pads, 2 battery pads. Board 18.00 x 23.50 mm. | U2 | ESP32-S3 Supermini | 1

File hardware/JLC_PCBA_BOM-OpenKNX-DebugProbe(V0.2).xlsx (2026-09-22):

Comment | Description | Value | Designator | Footprint | Quantity | JLCPCB Part #
B0505S-1W |  |  | A1 | B05_S-1WR3 | 1 | C7465127
10uF | Capacitor |  | C1, C9 | C0603 | 2 | C19702
47uF/10V | Capacitor |  | C2, C5, C6, C7 | C1206 | 4 | C96123
220uF/63V | Polarized Capacitor (Axial) |  | C3 | CAP-SMD_BD12.5-L13.0-W13.0-LS14.4-FD | 1 | C215762
100nF | Capacitor |  | C4, C8, C11 | C0603 | 3 | C14663
SS210 | Diode |  | D1, D2 | DO-214 | 2 | C14996
FS312F-G | Battery Protection IC |  | IC1 | SOT23-6 | 1 | C259720
12C02 | Switch_THT |  | J1 | SW-SMD_12C02 | 1 | C963206
Terminalblock X2 |  |  | J2 | Terminalblock_X2_3.5mm | 1 | C474892
Terminalblock X2 |  |  | J3 | Terminalblock_X2_5mm | 1 | C474881
Tactile Switch | Tactile Switch |  | J4 | TS-1088-AR02016 | 1 | C720477
100uH/500mA | Inductor |  | L1 | 5x5mm | 1 | C5274868
KNX | Wago 243-211 / KNX Klemme Schwarz/Rot |  | P1 | Wago 243-211 / KNX B/R | 1 | C19633675
AO3400A | 30V N-Channel MOSFET |  | Q1, Q2 | SOT23 Normal | 2 | C20917
100 | Resistor |  | R1 | R2512 | 1 | C309603
1k | Resistor |  | R2, R7 | R0603 | 2 | C21190
0 | Resistor |  | R3 | R0603 | 1 | C21189
1M | Resistor |  | R5, R6 | R1206 | 2 | C17927
100 | Resistor |  | R8 | R0603 | 1 | C22775
XL1509-5.0E1 | XL1509-5.0E1 |  | U1 | SOP8 | 1 | C61063
ESP32-S3 Supermini | ESP32-S3 SuperMini (nologo.tech). 18 castellated edge pins, 20 bottom-side test pads, 2 battery pads. Board 18.00 x 23.50 mm. |  | U2 | ESP32-S3 Supermini | 1

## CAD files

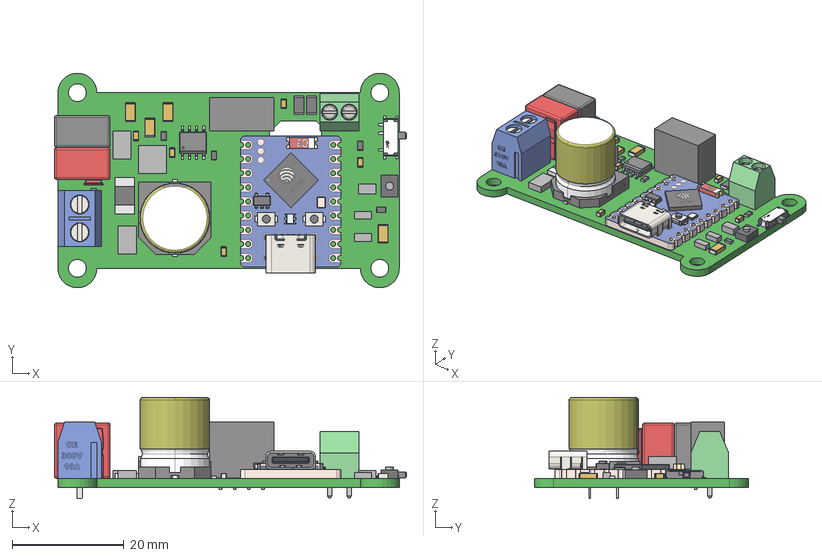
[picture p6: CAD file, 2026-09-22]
hardware/OpenKNX-DebugProbe(V0.2).step
63.1 x 38.4 x 18.2 mm

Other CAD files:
hardware/OpenKNXDebugProbe.f3z

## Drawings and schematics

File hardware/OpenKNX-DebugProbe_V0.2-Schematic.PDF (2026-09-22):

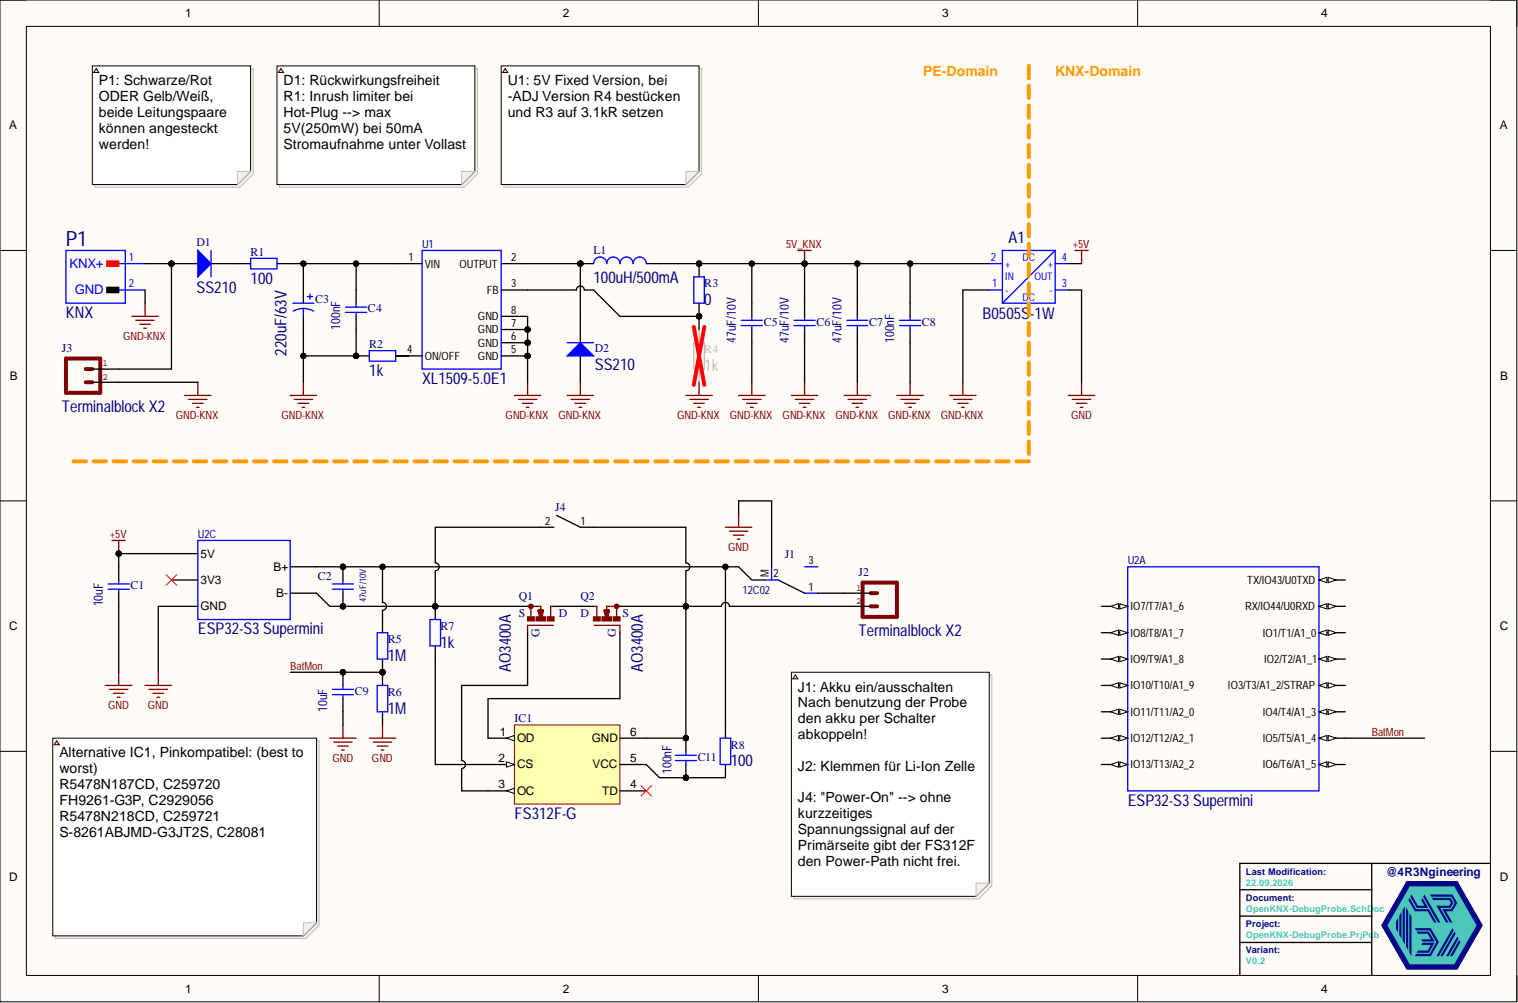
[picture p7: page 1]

P1: Schwarze/Rot
ODER Gelb/Wei
beide Leitungspaare können angesteckt

U1: 5V Fixed Version, bei -ADJ Version R4 bestücken

Akku ein/ausschalten
Nach benutzung der P
den akku per Schalter
abkoppeln!

kurzzeitiges Spannungssignal auf der Primärseite gibt der FS312F

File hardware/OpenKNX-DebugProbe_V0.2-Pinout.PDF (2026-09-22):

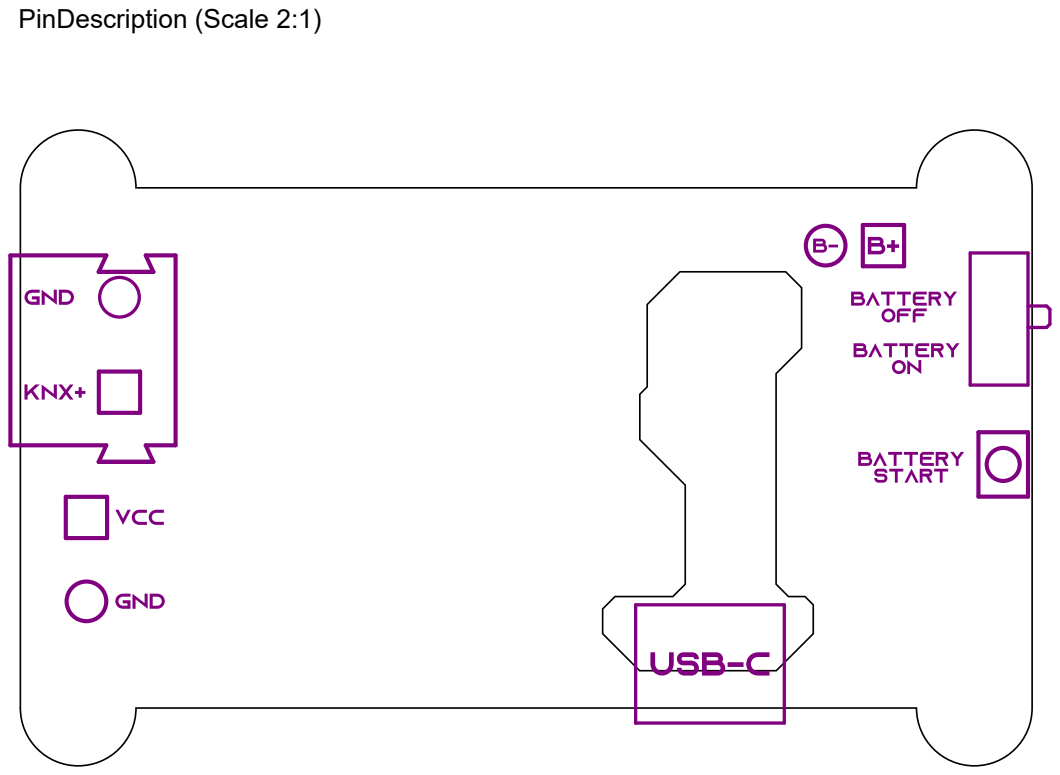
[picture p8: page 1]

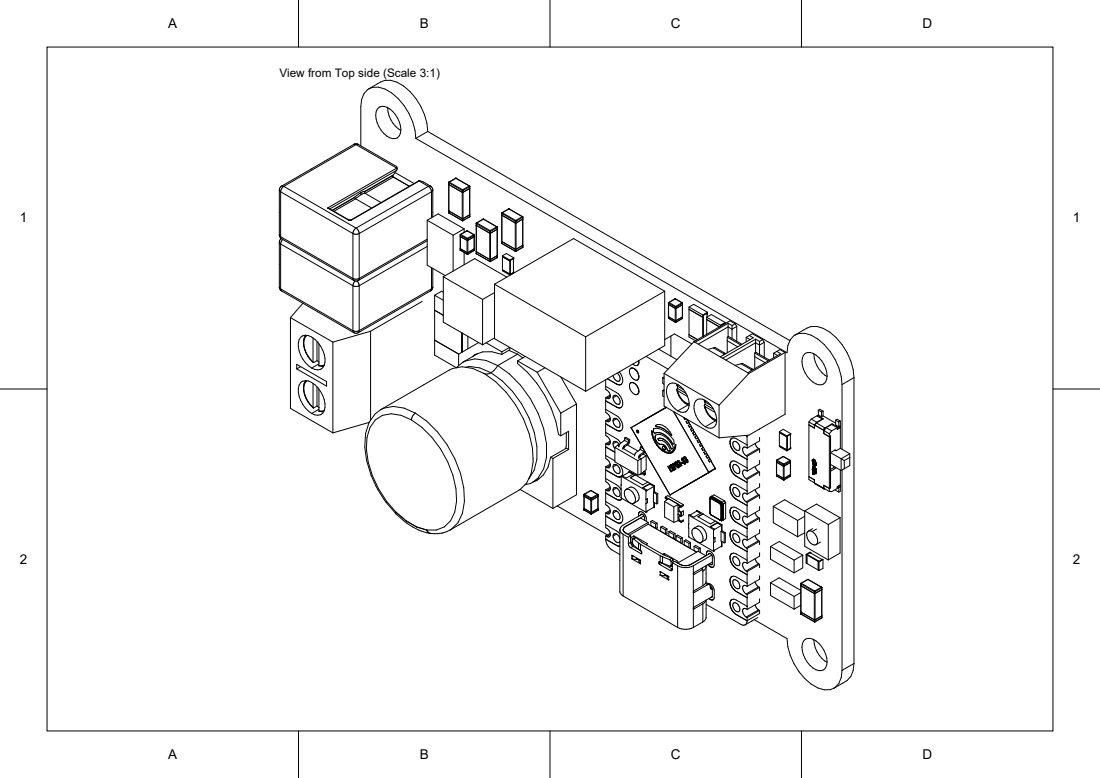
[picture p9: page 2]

View from Top side (Scale 3:1)

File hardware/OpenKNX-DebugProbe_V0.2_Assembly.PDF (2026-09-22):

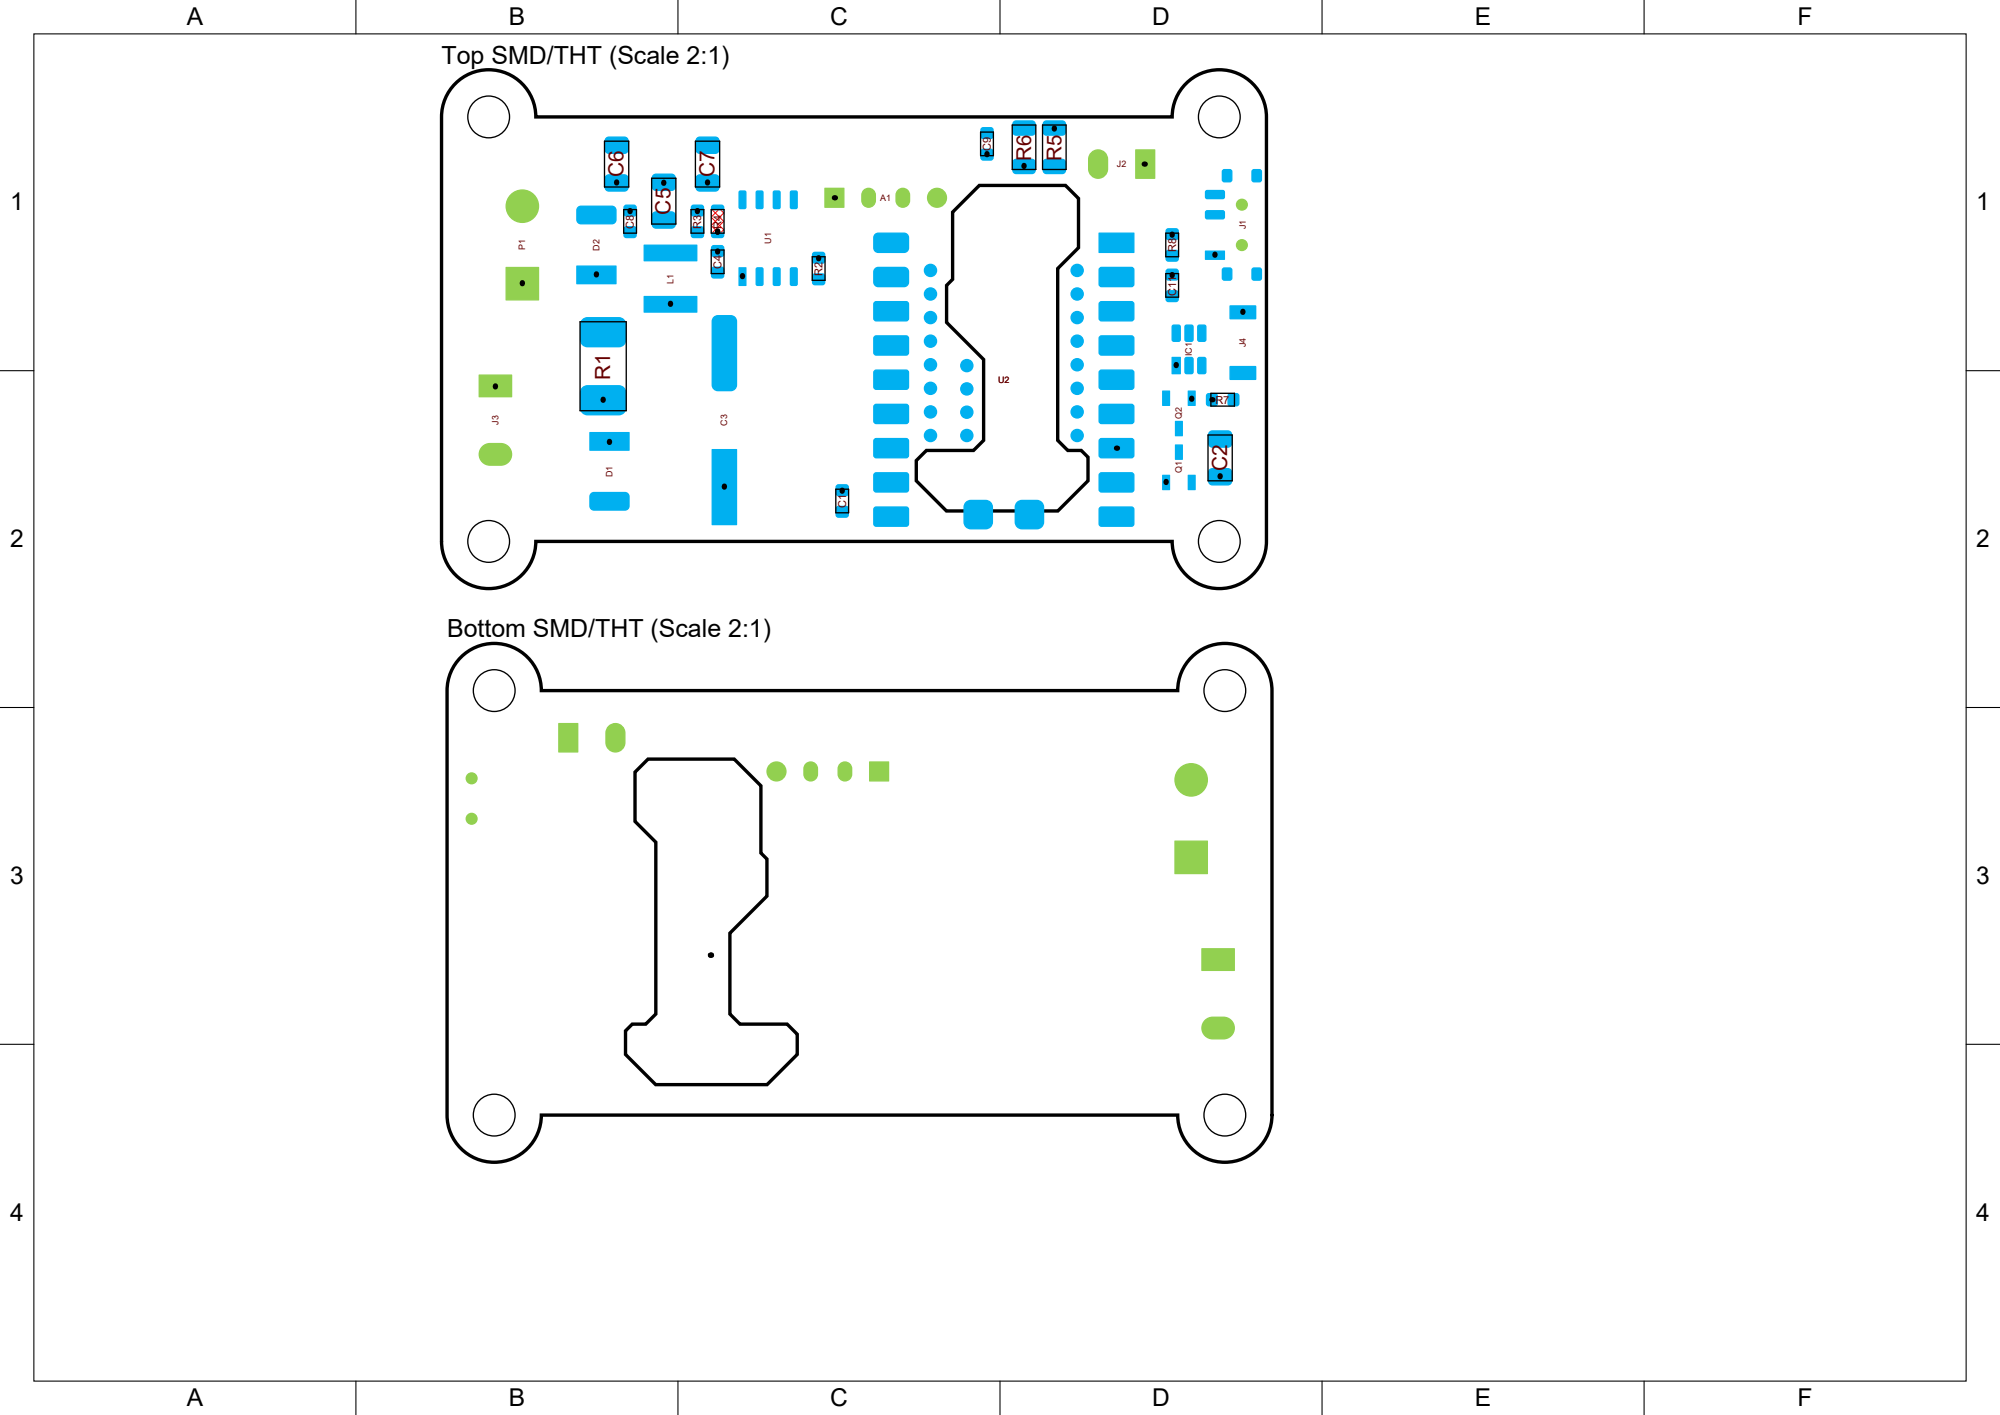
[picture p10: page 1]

Top SMD/THT (Scale 2:1)

Bottom SMD/THT (Scale 2:1)

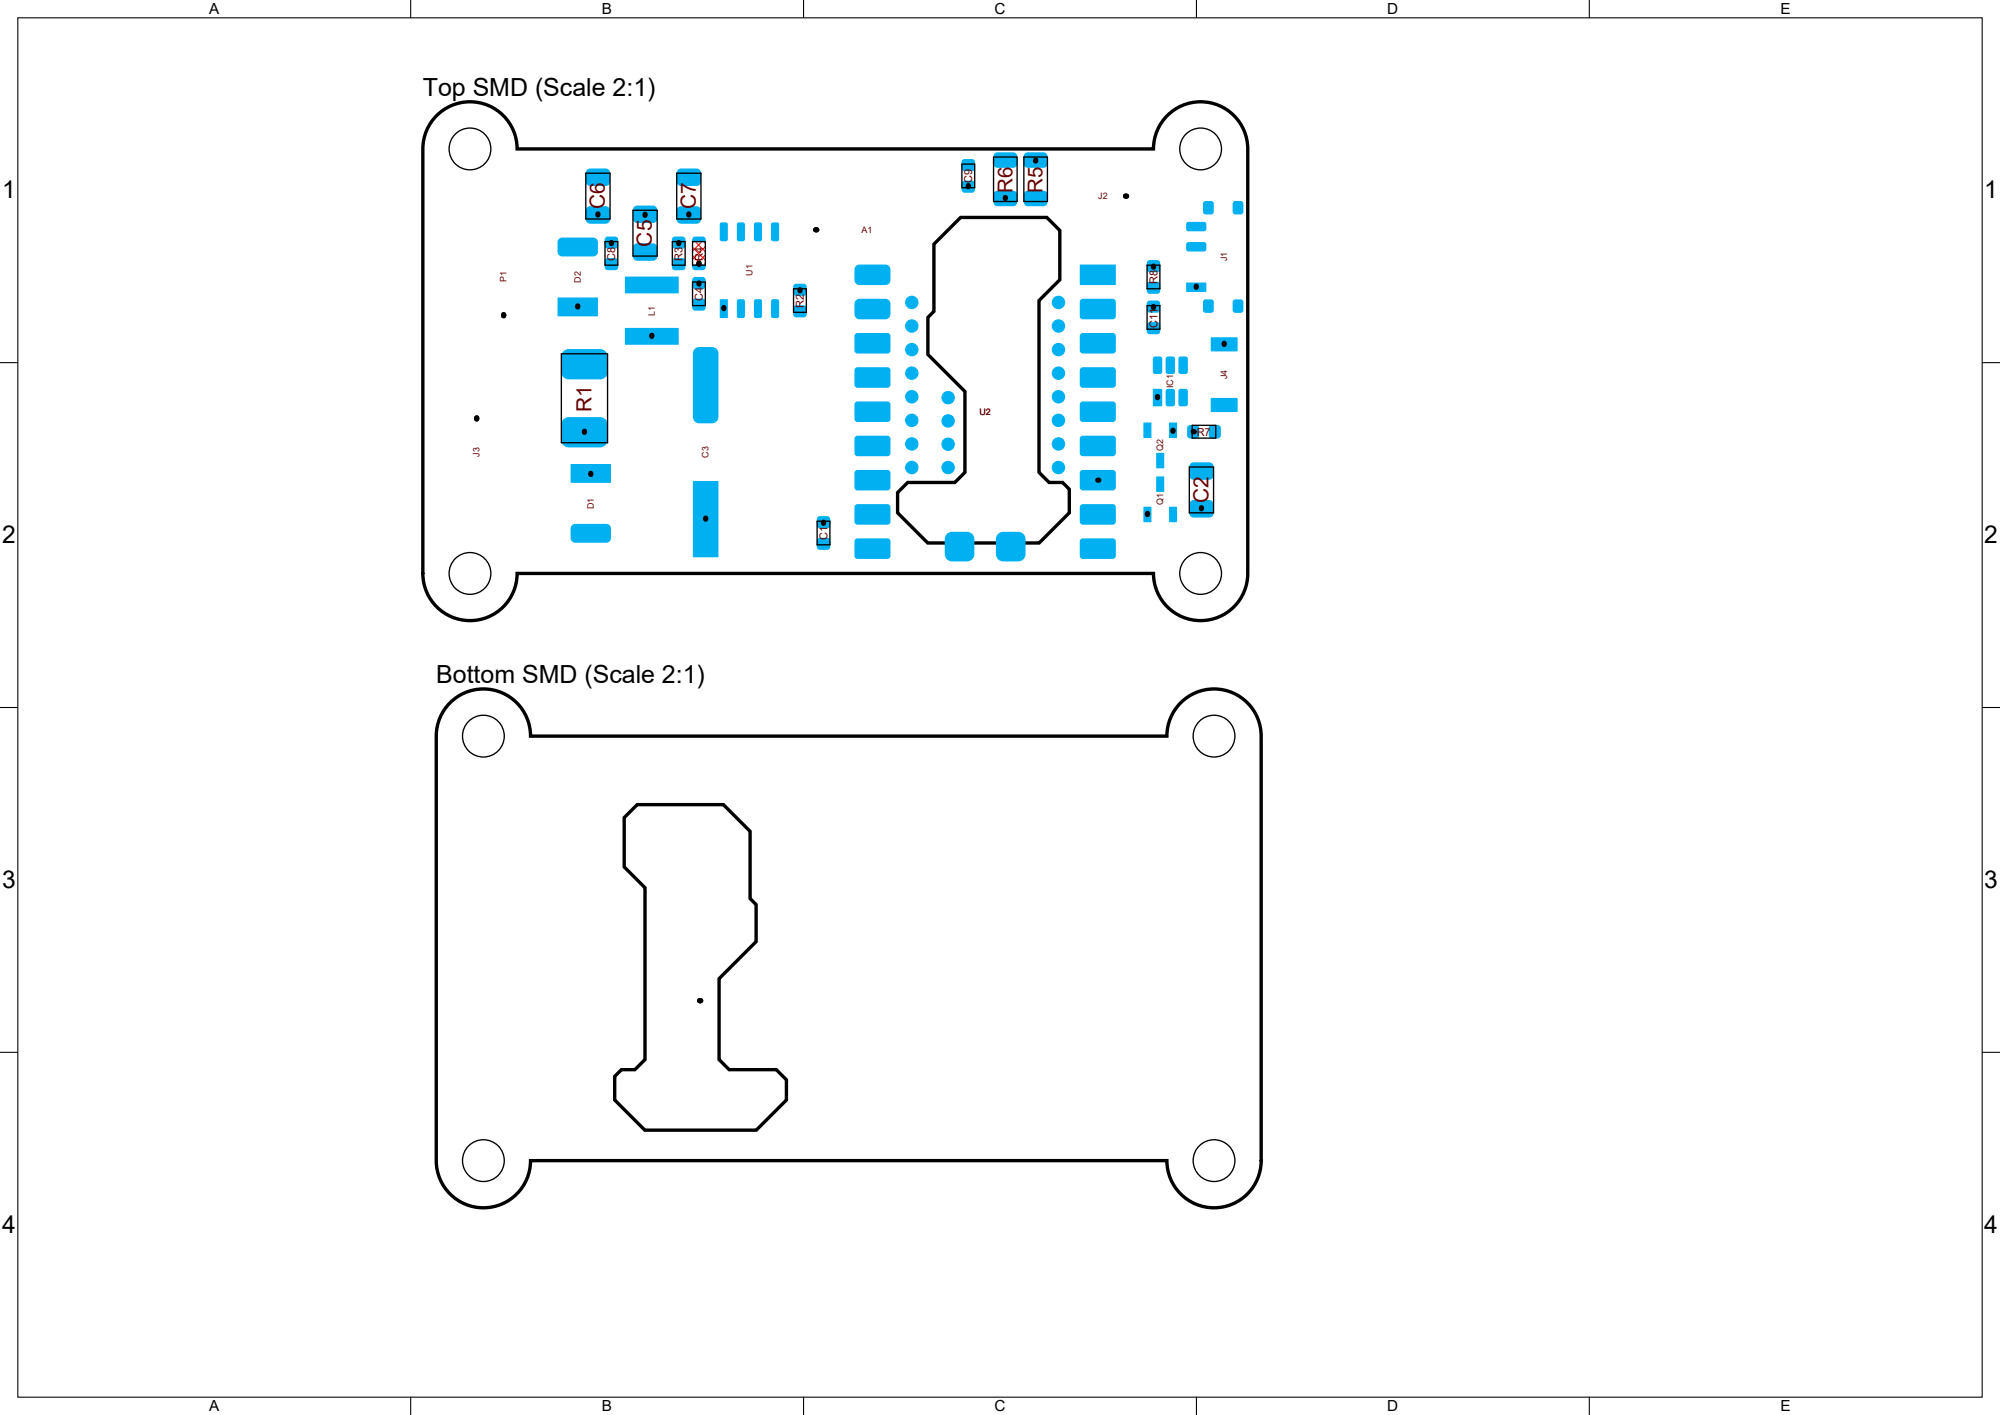
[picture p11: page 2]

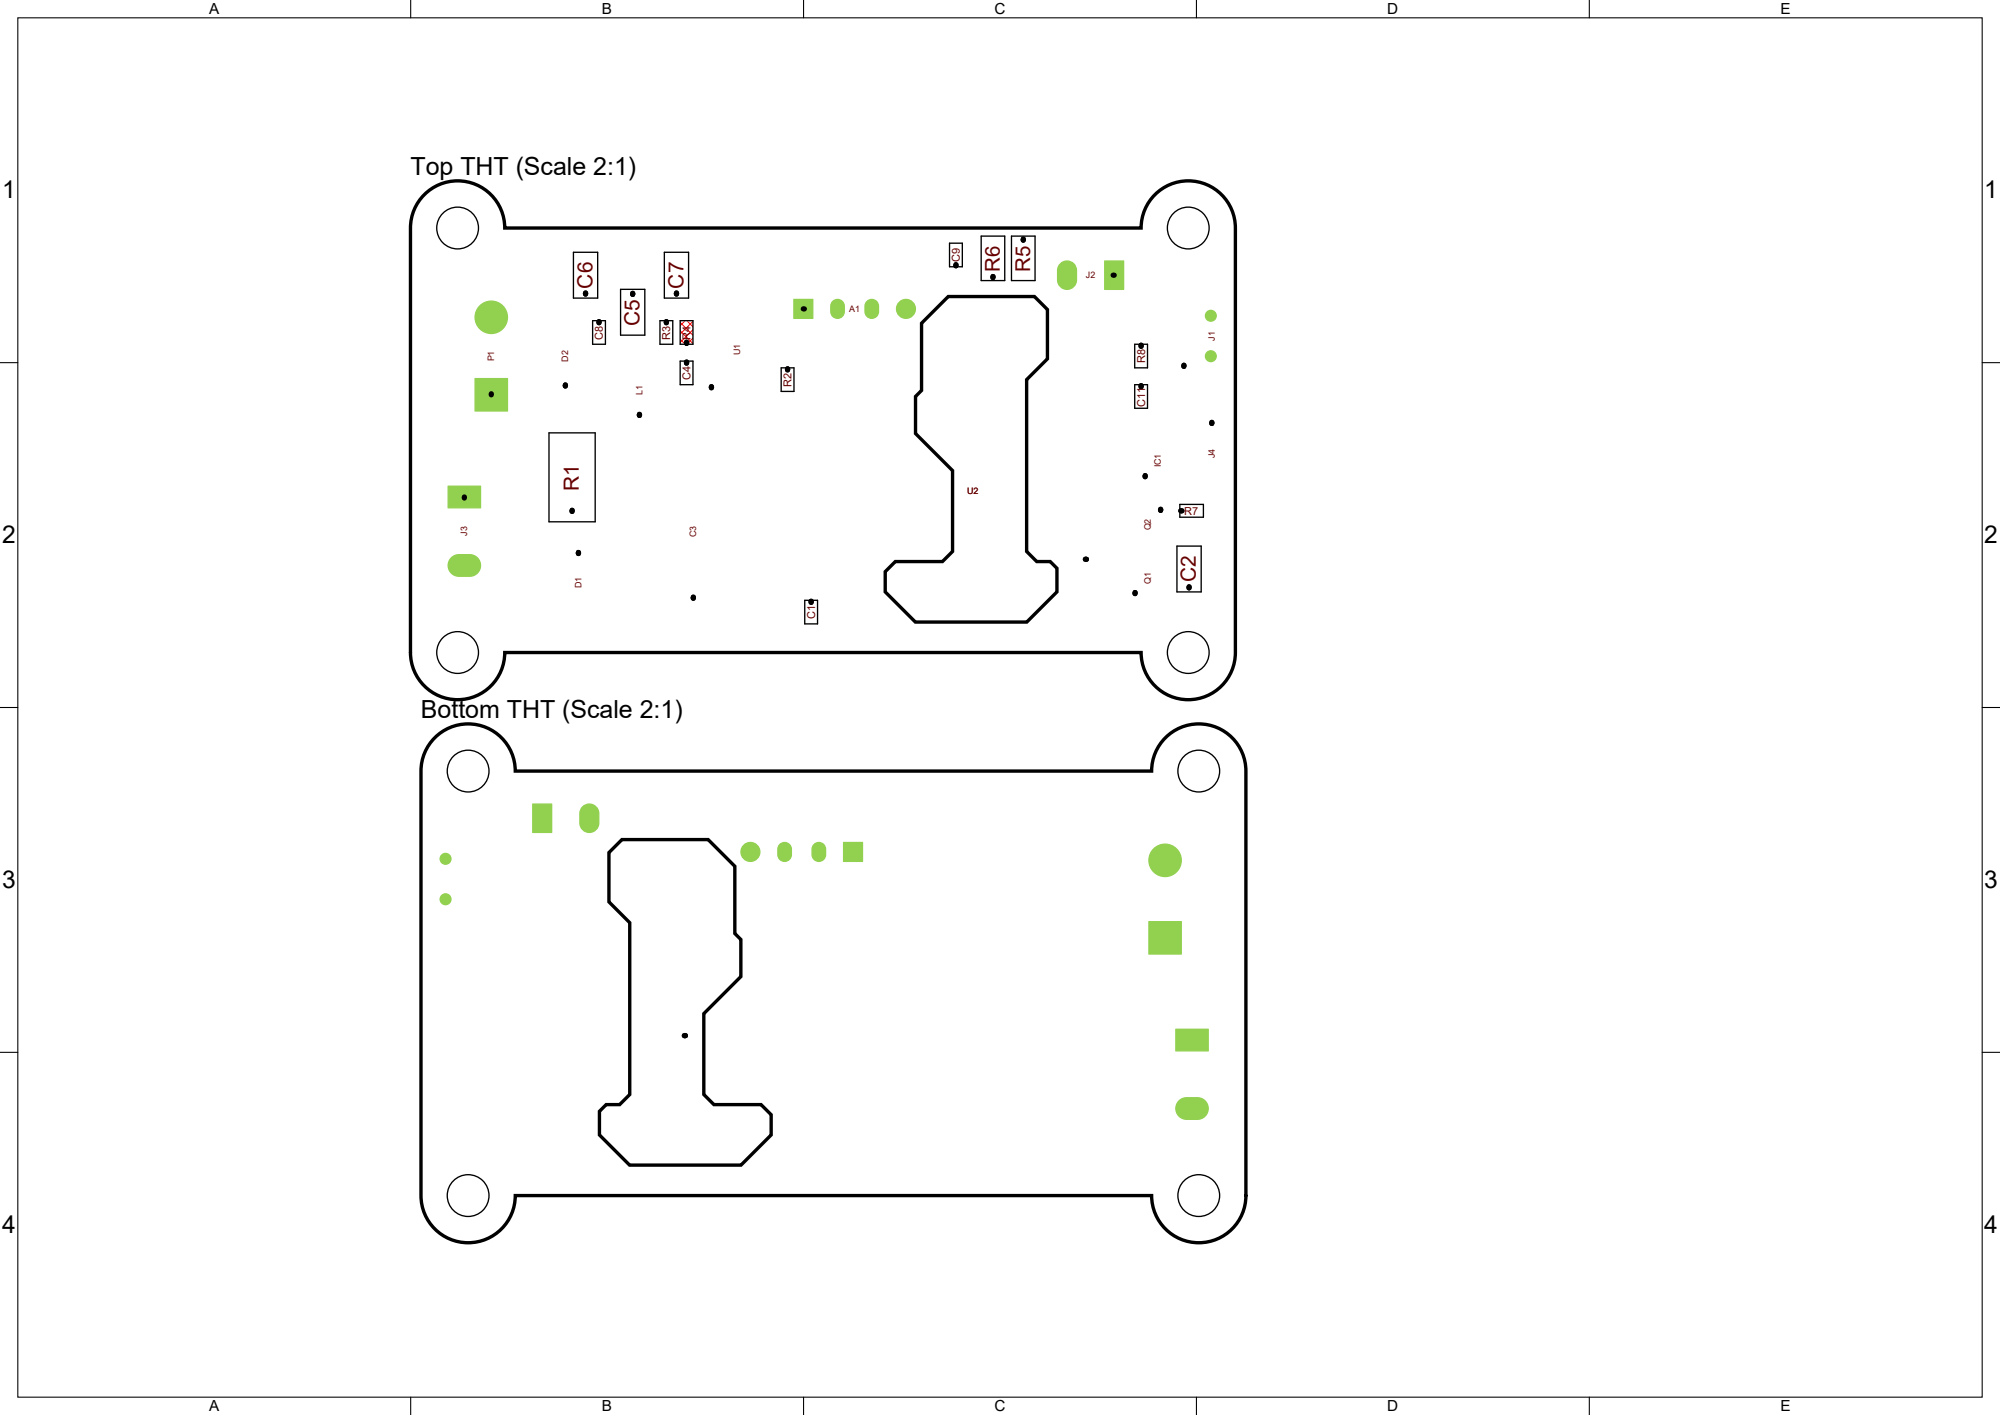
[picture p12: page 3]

A

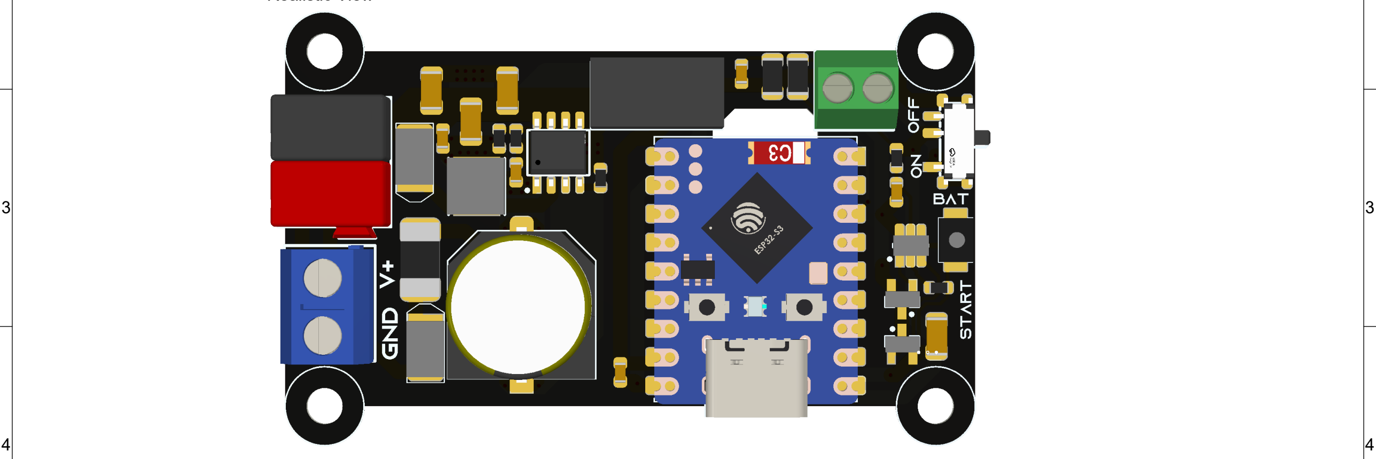
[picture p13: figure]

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
1 | 1
2 | 2
Realistic View

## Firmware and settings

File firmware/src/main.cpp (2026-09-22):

/**
 * OpenKNX DebugProbe — application entry point.
 *
 * Stufe 1: Probe ins Netz bringen und selbst aktualisierbar machen.
 * Stufe 2: USB-Host aktivieren und das angesteckte Zielgerät erkennen.
 *
 * Reihenfolge ist Absicht: WLAN und HTTP-Server stehen, bevor der USB-Host
 * angefasst wird. Hängt der USB-Stack, bleibt die Probe trotzdem per OTA
 * erreichbar. Stürzt er ab, greift der Rollback — deshalb wird das Image erst
 * NACH dem USB-Start bestätigt.
 */

#include <cstdio>
#include <cstdlib>
#include <cstring>
#include <string>
#include <vector>

#include "BatteryMonitor.hpp"
#include "OtaUpdater.hpp"
#include "Rfc2217Server.hpp"
#include "SerialBridge.hpp"
#include "Settings.hpp"
#include "StatusLed.hpp"
#include "Uf2Flasher.hpp"
#include "UsbTarget.hpp"
#include "AssetStore.hpp"
#include "B003Link.hpp"
#include "WebServer.hpp"
#include "WiFiManager.hpp"
#include "esp_heap_caps.h"
#include "esp_log.h"
#include "esp_system.h"
#include "esp_timer.h"
#include "freertos/FreeRTOS.h"
#include "freertos/task.h"

namespace {

constexpr const char* TAG = "main";

/// Seconds of healthy operation before a freshly flashed image is confirmed.
constexpr uint32_t PROBATION_SECONDS = 10;

/// Obergrenze fuer ein Kommando aus der Web-Konsole. Reichlich fuer alles, was
/// man tippt, und schuetzt davor, dass ein versehentlicher Datei-Upload auf
/// diesem Endpunkt landet.
constexpr size_t MAX_COMMAND_BYTES = 512;

struct AppContext
{
    Settings*     settings;
    WiFiManager*  wifi;
    OtaUpdater*   ota;
    UsbTarget*    usb;
    SerialBridge*  bridge;
    Rfc2217Server* rfc2217;
    StatusLed*     led;
    BatteryMonitor* battery;
};

/// Standardpin der RGB-LED auf den SuperMini-Varianten. Nur eine Vermutung —
/// deshalb in NVS ueberschreibbar, siehe handleLed().
constexpr int DEFAULT_LED_GPIO = 48;

/// NVS-Schluessel fuer den gefundenen Pin.
constexpr const char* KEY_LED_GPIO = "led_gpio";

/**
 * Solange ein solches Objekt lebt, blinkt die LED orange.
 *
 * RAII, weil handleFlash() ein halbes Dutzend Ausstiegspunkte hat. Ein
 * vergessenes Zuruecksetzen liesse die Warnung "nicht abstecken" fuer immer
 * stehen — und genau dann glaubt sie irgendwann niemand mehr.
 */
class FlashingIndicator
{
public:
    explicit FlashingIndicator(StatusLed* led) : m_led(led)
    {
        if (m_led != nullptr) m_led->setMode(StatusLed::Mode::Flashing);
    }
    ~FlashingIndicator()
    {
        // Zurueck auf einen aus dem Zustand abgeleiteten Modus kuemmert sich
        // die Aufsichtsschleife; hier genuegt es, die Warnung zu beenden.
        if (m_led != nullptr) m_led->setMode(StatusLed::Mode::Idle);
    }

    FlashingIndicator(const FlashingIndicator&)            = delete;
    FlashingIndicator& operator=(const FlashingIndicator&) = delete;

private:
    StatusLed* m_led;
};

AppContext g_ctx {};

std::string jsonString(const std::string& value)
{
    std::string out = "\"";
    for (const char c : value)
    {
        if (c == '"' || c == '\\')
            out += '\\';
        out += c;
    }
    out += '"';
    return out;
}

std::string hex16(uint16_t value)
{
    char buf[8];
    snprintf(buf, sizeof(buf), "0x%04X", value);
    return std::string("\"") + buf + "\"";
}

std::string hex8(uint8_t value)
{
    char buf[8];
    snprintf(buf, sizeof(buf), "0x%02X", value);
    return std::string("\"") + buf + "\"";
}

/// Escapt beliebige Bytes fuer ein JSON-String-Literal. Die Konsole des Ziels
/// enthaelt Steuerzeichen und ANSI-Sequenzen; die duerfen den JSON-Rahmen nicht
/// zerlegen.
std::string jsonEscapeBytes(const uint8_t* data, size_t length)
{
    static const char* HEX = "0123456789abcdef";

    std::string out;
    out.reserve(length + length / 4);

    for (size_t i = 0; i < length; ++i)
    {
        const uint8_t c = data[i];
        switch (c)
        {
            case '"':  out += "\\\""; break;
            case '\\': out += "\\\\"; break;
            case '\n': out += "\\n";  break;
            case '\r': out += "\\r";  break;
            case '\t': out += "\\t";  break;
            default:
                if (c < 0x20 || c == 0x7F)
                {
                    out += "\\u00";
                    out += HEX[(c >> 4) & 0x0F];
                    out += HEX[c & 0x0F];
                }
                else
                {
                    out += static_cast<char>(c);
                }
                break;
        }
    }
    return out;
}

std::string hex32(uint32_t value)
{
    char buf[16];
    snprintf(buf, sizeof(buf), "0x%08lX", static_cast<unsigned long>(value));
    return std::string("\"") + buf + "\"";
}

/**
 * Die fertigen Zeilen für die platformio.ini des Zielprojekts.
 *
 * Bewusst hier gebaut und nicht im Browser: `/api/snippet` und das Web-UI
 * sollen garantiert dasselbe liefern. Welcher Upload-Weg gilt, haengt am Ziel —
 * ein RP2040 wird per UF2 ueber HTTP geflasht, alles andere per esptool ueber
 * RFC2217.
 */
struct Snippet
{
    std::string comment;
    std::string monitor;
    std::string upload;
};

Snippet buildSnippet(const std::string& hostname, const UsbTarget& usb)
{
    const std::string host = hostname + ".local";

    Snippet snippet;
    snippet.monitor = "monitor_port  = socket://" + host + ":2323\n"
                      "monitor_speed = 115200";

    if (usb.state() != UsbTarget::State::Connected)
    {
        snippet.comment = "kein Zielgeraet angesteckt";
        return snippet;
    }

    const UsbTarget::DeviceInfo info = usb.device();

    char ids[24];
    snprintf(ids, sizeof(ids), "%04X:%04X", info.vid, info.pid);
    snippet.comment = info.description + " (" + ids + ")";

    if (info.vid == 0x2E8A)
    {
        // Ausdruecklich NICHT $SOURCE: PlatformIO loest das bei
        // upload_protocol = custom auf die firmware.bin auf, und die lehnt
        // /api/flash zu Recht ab. Die Klammern um ${PROGNAME} sind Pflicht --
        // "$PROGNAME.uf2" liest SCons als Attributzugriff und bricht ab.
        // --fail-with-body statt -f, damit der Grund einer Ablehnung im
        // PlatformIO-Log steht und nicht nur "curl: (22)".
        snippet.upload = "upload_protocol = custom\n"
                         "upload_command  = curl --fail-with-body --data-binary "
                         "\"@$BUILD_DIR/${PROGNAME}.uf2\" http://" +
                         host + "/api/flash";
    }
    else
    {
        // 460800 ist am Geraet mehrfach reproduziert; 921600 lief einmal
        // schneller und brach danach einmal ab.
        snippet.upload = "upload_port  = rfc2217://" + host + ":4000\n"
                         "upload_speed = 460800";
    }
    return snippet;
}

std::string snippetJson(const Snippet& s)
{
    auto asJson = [](const std::string& v) {
        return "\"" + jsonEscapeBytes(reinterpret_cast<const uint8_t*>(v.data()), v.size()) + "\"";
    };

    std::string json = "{";
    json += "\"comment\":" + asJson(s.comment);
    json += ",\"monitor\":" + asJson(s.monitor);
    json += ",\"upload\":" + asJson(s.upload);
    json += "}";
    return json;
}

/**
 * Warum die Probe das letzte Mal gestartet ist.
 *
 * Der Grund ueberlebt den Neustart im RTC-Speicher, und genau das macht ihn
 * wertvoll: ein Zielgeraet mit hohem Einschaltstrom kann die Probe per
 * Brownout zuruecksetzen, und hinterher ist nicht mehr zu sehen, ob es der
 * Strom war oder ein Absturz. `brownout` beantwortet das, ohne ein Bauteil und
 * ohne einen Blick auf die serielle Konsole.
 */
const char* resetReasonName()
{
    switch (esp_reset_reason())
    {
        case ESP_RST_POWERON:   return "poweron";
        case ESP_RST_SW:        return "software";      // z. B. nach einem OTA
        case ESP_RST_PANIC:     return "panic";
        case ESP_RST_INT_WDT:   return "int_wdt";
        case ESP_RST_TASK_WDT:  return "task_wdt";
        case ESP_RST_WDT:       return "wdt";
        case ESP_RST_DEEPSLEEP: return "deepsleep";
        case ESP_RST_BROWNOUT:  return "brownout";
        case ESP_RST_SDIO:      return "sdio";
        case ESP_RST_EXT:       return "extern";
        default:                return "unbekannt";
    }
}

std::string targetJson(const UsbTarget& usb)
{
    std::string json = "{";
    json += "\"state\":" + jsonString(usb.stateName());
    json += ",\"since_s\":" + std::to_string(usb.secondsInState());

    /*
     * Was fuer dieses Ziel moeglich ist, entscheidet die Probe - nicht das
     * Web-UI. Sonst muesste die Oberflaeche die Tabelle aus UsbTarget.hpp
     * nachbauen und liefe bei jedem neuen Geraetetyp hinterher. `*_how`
     * traegt bei `can_* == false` den Grund und steht im UI als Hinweis.
     */
    const UsbTarget::ResetSupport run  = usb.resetSupport(UsbTarget::ResetMode::Run);
    const UsbTarget::ResetSupport boot = usb.resetSupport(UsbTarget::ResetMode::Bootloader);
    json += ",\"can_reset\":" + std::string(run.possible ? "true" : "false");
    json += ",\"reset_how\":" + jsonString(run.how);
    json += ",\"can_bootmode\":" + std::string(boot.possible ? "true" : "false");
    json += ",\"bootmode_how\":" + jsonString(boot.how);

    if (usb.state() == UsbTarget::State::Connected)
    {
        const UsbTarget::DeviceInfo info = usb.device();
        json += ",\"description\":" + jsonString(info.description);
        json += ",\"vid\":" + hex16(info.vid);
        json += ",\"pid\":" + hex16(info.pid);
        json += ",\"kind\":" + jsonString(UsbTarget::kindName(info.kind));
        json += ",\"driver\":" + jsonString(UsbTarget::driverName(info.driver));
        json += ",\"manufacturer\":" + jsonString(info.manufacturer);
        json += ",\"product\":" + jsonString(info.product);
        json += ",\"serial\":" + jsonString(info.serial);
        json += ",\"speed\":" + jsonString(info.speed);
        json += ",\"class\":" + hex8(info.deviceClass);
        json += ",\"interface_class\":" + hex8(info.interfaceClass);
        json += ",\"serial_open\":" + std::string(usb.isSerialOpen() ? "true" : "false");
        json += ",\"baud\":" + std::to_string(usb.baudRate());
        // Steuert, ob das Web-UI den UF2-Bereich ueberhaupt anzeigt: nur ein
        // RP2040 laesst sich per UF2 flashen, egal ob er gerade laeuft oder
        // schon im BOOTSEL steht.
        json += ",\"uf2_capable\":" + std::string((info.vid == 0x2E8A) ? "true" : "false");
        json += ",\"msc_ready\":" + std::string(usb.isMscReady() ? "true" : "false");
        json += ",\"picoboot\":" + std::string(usb.hasPicoboot() ? "true" : "false");
        if (usb.isMscReady())
        {
            json += ",\"msc_kb\":" +
                    std::to_string((static_cast<uint64_t>(usb.mscSectorCount()) *
                                    usb.mscSectorSize()) / 1024);
        }
    }
    json += "}";
    return json;
}

std::string consoleJson(const SerialBridge& bridge, const Rfc2217Server& rfc)
{
    std::string json = "{";
    json += "\"port\":" + std::to_string(bridge.port());
    json += ",\"client\":" + jsonString(bridge.clientAddress());
    json += ",\"buffer\":" + std::to_string(bridge.bufferSize());
    json += ",\"rx\":" + std::to_string(bridge.bytesFromTarget());
    json += ",\"tx\":" + std::to_string(bridge.bytesToTarget());
    json += ",\"rfc2217_port\":" + std::to_string(rfc.port());
    json += ",\"rfc2217_client\":" + std::string(rfc.hasClient() ? "true" : "false");
    json += "}";
    return json;
}

/**
 * Die Zelle fuer `/api/status`.
 *
 * `level` ist der Zustand, `mv` die Zellenspannung, `pin_mv` die gemessene
 * Spannung am Teilerabgriff. Das Rohmass steht bewusst mit drin: weicht
 * `mv` von einem Multimeter ab, sagt `pin_mv` sofort, ob der Teiler anders
 * teilt als gedacht oder der ADC danebenliegt.
 *
 * `settled` ist waehrend der ersten rund 25 s nach dem Start false — so lange
 * laedt `C9` noch und die Messung liest zu niedrig.
 */
std::string batteryJson(const BatteryMonitor& bat)
{
    if (!bat.available()) return R"({"available":false})";

    std::string json = R"({"available":true)";
    json += ",\"level\":" + jsonString(BatteryMonitor::levelName(bat.level()));
    json += ",\"settled\":" + std::string(bat.warmedUp() ? "true" : "false");
    json += ",\"mv\":" + std::to_string(bat.millivolts());
    json += ",\"pin_mv\":" + std::to_string(bat.pinMillivolts());
    json += ",\"percent\":" + std::to_string(bat.percent());
    json += ",\"trim\":" + std::to_string(bat.trim());
    json += "}";
    return json;
}

esp_err_t handleStatus(httpd_req_t* req)
{
    const auto* ctx = static_cast<const AppContext*>(req->user_ctx);

    std::string json = "{";
    json += "\"name\":" + jsonString(ctx->wifi->hostname()) + ",";
    json += "\"version\":" + jsonString(ctx->ota->version()) + ",";
    json += "\"build\":" + jsonString(ctx->ota->buildTimestamp()) + ",";
    json += "\"partition\":" + jsonString(ctx->ota->runningPartition()) + ",";
    json += "\"pending_verify\":" + std::string(ctx->ota->isPendingVerify() ? "true" : "false") + ",";
    json += "\"reset_reason\":" + jsonString(resetReasonName()) + ",";
    json += "\"wifi\":" + jsonString(ctx->wifi->stateName()) + ",";
    // Warum es zuletzt nicht geklappt hat. Im Portal-Modus die einzige
    // Auskunft, die "falsches Passwort" von "Netz nicht da" trennt.
    json += "\"wifi_reason\":" +
            jsonString(WiFiManager::disconnectReasonName(
                ctx->wifi->lastDisconnectReason())) + ",";
    json += "\"usb_host\":" +
            std::string(ctx->usb->state() == UsbTarget::State::NotStarted ? "false" : "true") + ",";
    json += "\"ssid\":" + jsonString(ctx->wifi->ssid()) + ",";
    json += "\"rssi\":" + std::to_string(ctx->wifi->rssi()) + ",";
    json += "\"ip\":" + jsonString(ctx->wifi->ip()) + ",";
    json += "\"led\":{\"gpio\":" + std::to_string(static_cast<int>(ctx->led->pin())) +
            ",\"mode\":" + jsonString(StatusLed::modeName(ctx->led->mode())) + "},";
    json += "\"radio_awake\":" +
            std::string(ctx->wifi->isRadioAwake() ? "true" : "false") + ",";
    json += "\"battery\":" + batteryJson(*ctx->battery) + ",";
    json += "\"target\":" + targetJson(*ctx->usb) + ",";
    json += "\"console\":" + consoleJson(*ctx->bridge, *ctx->rfc2217) + ",";
    json += "\"snippet\":" +
            snippetJson(buildSnippet(ctx->wifi->hostname(), *ctx->usb)) + ",";
    json += "\"uptime_s\":" + std::to_string(esp_timer_get_time() / 1000000) + ",";
    json += "\"heap_free\":" + std::to_string(esp_get_free_heap_size());
    json += "}";

    return WebServer::sendJson(req, json);
}
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
extern "C" void app_main(void)
{
    static Settings    settings("probe");
    static WebServer   web;
    static AssetStore  assets;
    static OtaUpdater  ota;
    static WiFiManager  wifi(settings);
    static UsbTarget    usb;
    static SerialBridge  bridge;
    static Rfc2217Server rfc2217;
    static StatusLed     led;
    static BatteryMonitor battery;

    ESP_ERROR_CHECK(settings.begin());

    // Frueh, aber nicht fatal: ohne Teiler auf dem Board (Prototyp am
    // Steckbrett) schlaegt hier nichts fehl, die Messung meldet dann dauerhaft
    // "keine Zelle". Eine Probe am USB-Kabel laeuft genauso weiter.
    const esp_err_t batErr = battery.begin(settings);
    if (batErr != ESP_OK)
    {
        ESP_LOGW(TAG, "Zellenmessung nicht verfuegbar: %s", esp_err_to_name(batErr));
    }

    // Die LED so frueh wie moeglich: sie ist die einzige Rueckmeldung, solange
    // WLAN und Konsole noch nicht stehen.
    const auto ledGpio = static_cast<gpio_num_t>(
        settings.getU32(KEY_LED_GPIO, DEFAULT_LED_GPIO));
    const esp_err_t ledErr = led.begin(ledGpio);
    if (ledErr != ESP_OK)
    {
        ESP_LOGW(TAG, "status LED not available on GPIO%d: %s",
                 static_cast<int>(ledGpio), esp_err_to_name(ledErr));
    }

    ESP_LOGI(TAG, "OpenKNX DebugProbe %s (%s), running from '%s'",
             ota.version().c_str(), ota.buildTimestamp().c_str(), ota.runningPartition().c_str());
    if (ota.isPendingVerify())
    {
        ESP_LOGW(TAG, "image is on probation, will be confirmed in %u s", PROBATION_SECONDS);
    }

    WiFiManager::Config cfg;  // Defaults: 3 Versuche, sonst Notfall-Portal
    ESP_ERROR_CHECK(wifi.init(cfg));

    ESP_ERROR_CHECK(web.begin(80, 20));

    // Die Oberflaeche liegt im LittleFS, nicht mehr im Firmware-Image.
    // Ein Fehlschlag ist nicht fatal: AssetStore liefert dann die
    // eingebaute Notfallseite aus.
    const esp_err_t assetsErr = assets.mount();
    if (assetsErr != ESP_OK)
    {
        ESP_LOGW(TAG, "Web-Assets nicht verfuegbar: %s", esp_err_to_name(assetsErr));
    }

    g_ctx = AppContext{&settings, &wifi, &ota, &usb, &bridge, &rfc2217, &led, &battery};
    ESP_ERROR_CHECK(web.on("/api/status", HTTP_GET, &handleStatus, &g_ctx));
    ESP_ERROR_CHECK(web.on("/api/flash", HTTP_POST, &handleFlash, &g_ctx));
    ESP_ERROR_CHECK(web.on("/api/reset", HTTP_POST, &handleReset, &g_ctx));
    ESP_ERROR_CHECK(web.on("/api/bootmode", HTTP_POST, &handleBootmode, &g_ctx));
    // Alter Name aus der Zeit, als es nur den RP2040-Touch gab.
    ESP_ERROR_CHECK(web.on("/api/bootsel", HTTP_POST, &handleBootmode, &g_ctx));
    ESP_ERROR_CHECK(web.on("/api/led", HTTP_POST, &handleLed, &g_ctx));
    ESP_ERROR_CHECK(web.on("/api/battery/calibrate", HTTP_POST, &handleBatteryCalibrate, &g_ctx));
    ESP_ERROR_CHECK(web.on("/api/console", HTTP_POST, &handleConsoleSend, &g_ctx));
    ESP_ERROR_CHECK(web.on("/api/console", HTTP_GET, &handleConsole, &g_ctx));
    ESP_ERROR_CHECK(web.on("/api/snippet", HTTP_GET, &handleSnippet, &g_ctx));
    ESP_ERROR_CHECK(web.on("/api/ch32", HTTP_GET, &handleCh32, &g_ctx));
    ESP_ERROR_CHECK(web.on("/api/ch32/flash", HTTP_POST, &handleCh32Flash, &g_ctx));
    ota.registerRoutes(web);

    // Decides between joining the stored network and opening the setup portal;
    // registerRoutes() needs to know the outcome.
    ESP_ERROR_CHECK(wifi.start());
    wifi.registerRoutes(web);

    if (wifi.state() != WiFiManager::State::Portal)
    {
        // ZULETZT: die Wildcard-Route "/*" wuerde sonst die /api-Routen
        // verschlucken — esp_http_server nimmt den ersten passenden
        // Handler in Registrierungsreihenfolge.
        ESP_ERROR_CHECK(assets.registerRoutes(web));
        ESP_LOGI(TAG, "ready: http://%s.local/", wifi.hostname().c_str());
    }

    // Der Startvorgang ist ab hier auf jeden Fall nachvollziehbar: steht das
    // WLAN, per HTTP; steht es nicht, ueber die sekundaere Konsole am USB.
    wifi.logDiagnostics();

    // Erst jetzt den USB-Host starten: OTA ist ab hier erreichbar, und ein
    // Absturz hier führt zum Rollback statt zu einer toten Probe.
    //
    // UND erst, wenn das WLAN steht — der Host-Modus kostet den USB-Serial-JTAG
    // und damit die letzte Auskunftsmoeglichkeit einer Probe ohne Netz.
    // Begruendung in voller Laenge bei usbGateTask().
    if (wifi.state() == WiFiManager::State::Connected)
    {
        startUsbStack(g_ctx);
    }
    else
    {
        xTaskCreatePinnedToCore(&usbGateTask, "usb_gate", 3584, &g_ctx, 3, nullptr, 0);
    }

    // Erst jetzt starten: der Task liest bridge und rfc2217.
    if (led.isRunning())
    {
        xTaskCreatePinnedToCore(&ledSupervisorTask, "led_sup", 2560, &g_ctx, 2, nullptr, 0);
    }

    // Reaching a stable state — online or portal — counts as a healthy boot.
    // The rollback guards against crash loops, not against a missing access point.
    vTaskDelay(pdMS_TO_TICKS(PROBATION_SECONDS * 1000));
    ota.confirmRunningImage();
}

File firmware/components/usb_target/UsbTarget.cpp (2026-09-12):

#include "UsbTarget.hpp"

#include <cstdio>
#include <cstring>

#include "esp_log.h"
#include "esp_timer.h"
#include "usb/usb_helpers.h"
#include "usb/vcp.hpp"
#include "usb/vcp_ch34x.hpp"
#include "usb/vcp_cp210x.hpp"
#include "usb/vcp_ftdi.hpp"

namespace {

constexpr const char* TAG = "usb";

constexpr uint8_t USB_CLASS_CDC_      = 0x02;
constexpr uint8_t USB_CLASS_HID_      = 0x03;
constexpr uint8_t USB_CLASS_MSC_      = 0x08;
constexpr uint8_t USB_CLASS_HUB_      = 0x09;
constexpr uint8_t USB_CLASS_CDC_DATA_ = 0x0A;
constexpr uint8_t USB_CLASS_MISC_     = 0xEF;
constexpr uint8_t USB_CLASS_VENDOR_   = 0xFF;

constexpr uint16_t ANY_PID = 0xFFFF;

/// VID von Raspberry Pi. Nur diese Geraete kennen den 1200-Baud-Touch.
constexpr uint16_t VID_RASPBERRY = 0x2E8A;

/// VID von Espressif. Deren Chips mit nativem USB werten DTR und RTS im
/// USB-Serial-JTAG selbst aus, brauchen aber eine andere Folge als die
/// Transistorschaltung auf den Bridge-Boards.
constexpr uint16_t VID_ESPRESSIF = 0x303A;

/// Wie lange EN beim Reset unten bleibt (esptool: 100 ms).
constexpr uint32_t RESET_HOLD_MS = 100;

/// Wie lange IO0 nach dem Loslassen von EN noch unten bleibt, damit der Chip
/// den Pegel beim Hochlaufen sicher abtastet (esptool: 50 ms).
constexpr uint32_t BOOT_HOLD_MS = 50;

/// Schrittweite der USB-Serial-JTAG-Folge (esptool: 100 ms je Schritt).
constexpr uint32_t JTAG_STEP_MS = 100;

/// Der USB-Serial-JTAG haengt am selben Kabel wie die Daten: nach einem Reset
/// muss sich der Port erst neu melden. esptool wartet hier 200 ms.
constexpr uint32_t JTAG_SETTLE_MS = 200;

/*
 * PICOBOOT — das Vendor-Interface des RP2040-Boot-ROMs. Werte aus
 * `boot/picoboot.h` des pico-sdk, nicht aus dem Gedaechtnis:
 * Magic, Control-Request zum Ruecksetzen des Interface, Kommando-ID, und die
 * Feldoffsets des 32 Byte grossen Kommandopakets.
 */
constexpr uint32_t PICOBOOT_MAGIC    = 0x431FD10Bu;
constexpr uint8_t  PICOBOOT_IF_RESET = 0x41;  ///< Control OUT, wLength 0
constexpr uint8_t  PC_REBOOT         = 0x02;
constexpr size_t   PICOBOOT_CMD_LEN  = 32;

/// Vorlauf, den das Boot-ROM vor dem Neustart wartet. Lang genug, dass die
/// Quittung noch durchkommt, kurz genug, dass es sich sofort anfuehlt.
constexpr uint32_t PICOBOOT_DELAY_MS = 100;

/// Geduld fuer einen einzelnen PICOBOOT-Transfer.
constexpr uint32_t PICOBOOT_TIMEOUT_MS = 1000;

/*
 * HID-Klassenrequests (USB HID 1.11, 7.2). Feature-Reports laufen als
 * Steuertransfer ueber Endpunkt 0 — dafuer braucht es keinen HID-Treiber.
 */
constexpr uint8_t  HID_REQ_GET_REPORT = 0x01;
constexpr uint8_t  HID_REQ_SET_REPORT = 0x09;
constexpr uint16_t HID_REPORT_FEATURE = 0x03;

/// VID von pid.codes. Der rv003usb-Bootloader meldet sich darunter.
constexpr uint16_t VID_PIDCODES     = 0x1209;
constexpr uint16_t PID_RV003USB_BL  = 0xB003;

void put32(uint8_t* p, uint32_t v)
{
    p[0] = static_cast<uint8_t>(v);
    p[1] = static_cast<uint8_t>(v >> 8);
    p[2] = static_cast<uint8_t>(v >> 16);
    p[3] = static_cast<uint8_t>(v >> 24);
}

/// Wie lange DTR beim Touch aktiv bleibt, bevor es wieder abfaellt.
constexpr uint32_t TOUCH_HOLD_MS = 50;

/// Wartezeit auf den Massenspeicher nach einem Touch (docs/architecture.md).
constexpr uint32_t MSC_TIMEOUT_MS = 5000;

/// Ein Versuch und ein Retry — mehr bringt nichts, wenn die Firmware den
/// Touch gar nicht auswertet.
constexpr uint32_t TOUCH_ATTEMPTS = 2;

struct KnownDevice
{
    uint16_t             vid;
    uint16_t             pid;  ///< ANY_PID = beliebig, muss dann zuletzt stehen
    const char*          name;
    UsbTarget::Kind      kind;
    UsbTarget::Driver    driver;
};

/**
 * Reihenfolge zählt: der erste Treffer gewinnt, deshalb stehen die konkreten
 * PIDs vor dem ANY_PID-Eintrag desselben Herstellers.
 */
constexpr KnownDevice KNOWN_DEVICES[] = {
    // --- Raspberry Pi / RP2040 ---------------------------------------------
    {0x2E8A, 0x0003, "RP2040 im BOOTSEL-Modus",       UsbTarget::Kind::Bootsel,      UsbTarget::Driver::Msc},
    {0x2E8A, 0x000A, "Raspberry Pi Pico (USB-CDC)",   UsbTarget::Kind::Cdc,          UsbTarget::Driver::CdcAcm},
    {0x2E8A, 0x0009, "RP2040 (Pico SDK, CDC)",        UsbTarget::Kind::Cdc,          UsbTarget::Driver::CdcAcm},
    {0x2E8A, 0x00C0, "Raspberry Pi Pico (Arduino)",   UsbTarget::Kind::Cdc,          UsbTarget::Driver::CdcAcm},
    {0x2E8A, ANY_PID, "Raspberry Pi RP2040",          UsbTarget::Kind::Cdc,          UsbTarget::Driver::CdcAcm},

    // --- Espressif (für die künftigen netzwerkfähigen OpenKNX-Geräte) ------
    {0x303A, 0x1001, "ESP32 USB-Serial/JTAG",         UsbTarget::Kind::Cdc,          UsbTarget::Driver::CdcAcm},
    {0x303A, 0x0002, "ESP32-S2 USB-CDC",              UsbTarget::Kind::Cdc,          UsbTarget::Driver::CdcAcm},
    {0x303A, 0x1000, "ESP32-S2 (TinyUSB)",            UsbTarget::Kind::Cdc,          UsbTarget::Driver::CdcAcm},
    {0x303A, ANY_PID, "Espressif ESP32 (USB)",        UsbTarget::Kind::Cdc,          UsbTarget::Driver::CdcAcm},

    // --- USB-UART-Bridges: vendor-specific, NICHT CDC ----------------------
    {0x1A86, 0x7523, "USB-UART-Bridge CH340",         UsbTarget::Kind::SerialBridge, UsbTarget::Driver::Ch34x},
    {0x1A86, 0x5523, "USB-UART-Bridge CH341",         UsbTarget::Kind::SerialBridge, UsbTarget::Driver::Ch34x},
    {0x1A86, 0x55D3, "USB-UART-Bridge CH343",         UsbTarget::Kind::SerialBridge, UsbTarget::Driver::Ch34x},
    {0x1A86, 0x55D4, "USB-UART-Bridge CH9102",        UsbTarget::Kind::SerialBridge, UsbTarget::Driver::Ch34x},
    {0x1A86, ANY_PID, "USB-UART-Bridge (WCH)",        UsbTarget::Kind::SerialBridge, UsbTarget::Driver::Ch34x},

    {0x10C4, 0xEA60, "USB-UART-Bridge CP2102",        UsbTarget::Kind::SerialBridge, UsbTarget::Driver::Cp210x},
    {0x10C4, 0xEA70, "USB-UART-Bridge CP2105",        UsbTarget::Kind::SerialBridge, UsbTarget::Driver::Cp210x},
    {0x10C4, 0xEA71, "USB-UART-Bridge CP2108",        UsbTarget::Kind::SerialBridge, UsbTarget::Driver::Cp210x},
    {0x10C4, ANY_PID, "USB-UART-Bridge (Silicon Labs)", UsbTarget::Kind::SerialBridge, UsbTarget::Driver::Cp210x},

    {0x0403, 0x6001, "USB-UART-Bridge FT232R",        UsbTarget::Kind::SerialBridge, UsbTarget::Driver::Ftdi},
    {0x0403, 0x6010, "USB-UART-Bridge FT2232",        UsbTarget::Kind::SerialBridge, UsbTarget::Driver::Ftdi},
    {0x0403, 0x6014, "USB-UART-Bridge FT232H",        UsbTarget::Kind::SerialBridge, UsbTarget::Driver::Ftdi},
    {0x0403, 0x6015, "USB-UART-Bridge FT230X",        UsbTarget::Kind::SerialBridge, UsbTarget::Driver::Ftdi},
    {0x0403, ANY_PID, "USB-UART-Bridge (FTDI)",       UsbTarget::Kind::SerialBridge, UsbTarget::Driver::Ftdi},

    {0x067B, 0x2303, "USB-UART-Bridge PL2303",        UsbTarget::Kind::SerialBridge, UsbTarget::Driver::Pl2303},

    // --- sonstige, die im OpenKNX-Umfeld auftauchen können -----------------
    {0x0483, 0x5740, "STM32 Virtual COM Port",        UsbTarget::Kind::Cdc,          UsbTarget::Driver::CdcAcm},
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

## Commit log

2026-08-23 OpenKNX DebugProbe: WLAN-Debugger auf ESP32-S3
    Ein USB-C-Kabel am OpenKNX-Geraet, alles Weitere ueber WLAN:
    - serielle Konsole des Ziels ueber TCP 2323, mit Mitschnittpuffer,
    ueberlebt Resets des Ziels
    - RFC2217 auf Port 4000 (Baudrate + DTR/RTS) fuer esptool & Co.
    - UF2 per HTTP ins RP2040-Ziel, ueber USB-MSC geschrieben,
    Weg nach BOOTSEL per 1200-Baud-Touch
    - Selbst-Update der Probe per OTA mit A/B-Slots und Rollback
    - WLAN-Einrichtung ueber Captive Portal, mDNS, Web-UI
    Stufen 1 bis 5 am Geraet verifiziert. Gebaut mit PlatformIO und
    framework = espidf.
    [partitions.csv]
2026-08-24 Status-LED, englische Doku, Hardware-Ordner mit Schaltplan
    RGB-LED des Moduls als Betriebsanzeige: neue Komponente status_led mit einem
    WS2812 an GPIO48 (am Geraet bestaetigt). Sechs Zustaende nach Dringlichkeit,
    flashing gewinnt gegen alles, weil dort ein Abziehen des Kabels Schaden
    anrichtet: flashing orange blinkend, battery_low rot im Sekundentakt, no_wifi
    rot pulsierend, busy gelb, target_ready gruen, idle gruen pulsierend.
    battery_low ist gerendert, wird aber von nichts gesetzt -- die Zellenmessung
    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
2026-08-24 README: eigene Ueberschrift fuer die PlatformIO-Integration
    Der Block zur platformio.ini des Zielprojekts hing ohne Ueberschrift hinter dem
    LED-Abschnitt. Bewusst nicht mit 'Build and flash' zusammengelegt: das baut die
    Firmware der Probe, hier geht es um die Konfiguration im Zielprojekt.
2026-08-24 hardware.md nach README.md umbenannt
    GitHub zeigt beim Wechsel in einen Ordner automatisch dessen README.md an;
    hardware.md blieb dort unsichtbar. Die vier Verweise mitgezogen: aus docs/ und
    den ADRs jetzt auf den Ordner statt auf die Datei, damit der Link auch nach
    einer weiteren Umbenennung haelt.
2026-08-24 README: die zwei Onboard-LEDs des SuperMini dokumentiert
    Rote LED leuchtet nur bei externer Versorgung, nicht im Akkubetrieb -- damit
    zeigt sie, welche Quelle das Board speist. Blaue LED kommt vom Li-Ion-Lader:
    an beim Laden, aus bei voller Zelle, blinkend ohne Zelle.
    Dazu die Erklaerung zu battery_low wieder eingesetzt; die Tabellenzeile
    verwies auf ein 'see below', das nicht mehr vorhanden war.
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2026-08-24 README: rote Onboard-LED richtiggestellt, sie haengt an GPIO48
    Die vorherige Fassung nannte sie eine Betriebsanzeige fuer externe Versorgung.
    Das war falsch: sie teilt GPIO48 mit dem WS2812 und ist dunkel, sobald die
    Firmware die Status-LED treibt. Am Geraet nachgewiesen -- Status-LED auf einen
    anderen Pin legen holt die rote zurueck, zurueck auf 48 schaltet sie wieder aus.
2026-08-25 StatusLed: alten Strip beim Pinwechsel dunkel schalten
    Ein WS2812 ist ein Latch -- ohne neue Daten haelt er seine letzte Farbe
    unbegrenzt. setPin() baute bisher den neuen Strip auf und schloss den alten,
    ohne ihn zu loeschen; die LED am alten Pin fror damit auf ihrer letzten Farbe
    ein, bis das Board stromlos wurde. Beim Suchen des geteilten GPIO48 gut zu
    sehen gewesen.
2026-09-02 hardware: Fertigungsdaten fuer V0.1 ergaenzt
    - Gerber-Paket, JLC-PCBA-BOM und -CPL
    - STEP-Modell der bestueckten Platine
    - Pinout- und Assembly-PDF
    - Schaltplan-PDF auf den aktuellen Stand gebracht
    [JLC_PCBA_BOM-OpenKNX-DebugProbe(V0.1).xlsx, OpenKNX-DebugProbe(V0.1).step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]
2026-09-11 Ziel neu starten und in den Bootmodus schicken, Oberflaeche per WLAN
    Zwei Knoepfe im Web-UI und zwei Endpunkte: POST /api/reset startet das
    Zielgeraet in seine Anwendung, POST /api/bootmode haelt es im Bootlader an.
    /api/bootsel bleibt als alter Name auf demselben Handler.
    Einen gemeinsamen Mechanismus gibt es dafuer nicht, deshalb entscheidet die
    Probe und nicht das Web-UI: /api/status liefert can_reset, reset_how,
    can_bootmode und bootmode_how. Bei can_* == false traegt *_how den Grund,
    und das UI schreibt ihn unter die gesperrten Knoepfe.
    UART-Bridge RTS-Puls auf EN DTR/RTS-Folge auf IO0 und EN
    USB-Serial-JTAG RTS-Puls DTR/RTS-Folge mit Boot-Latch
    RP2040 (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
    [partitions.csv]
2026-09-12 CH32V003: Erkennung, Bootmodus und das B003-Protokoll in der Probe
    Der CH32V003 stand in ADR-0005 als ausserhalb, begruendet mit "kein USB".
    Mit cnlohrs rv003usb-Bootloader bitbangt der Chip USB selbst und ist damit
    genau das, was die Regel erlaubt: ein Ziel, das ueber seine eigene
    USB-Schnittstelle ansprechbar ist.
    Erkennung: 1209:B003 wird benannt, neue Kind::HidBootloader und
    Driver::HidRaw. Der ESP32-S3-Host enumeriert das bitgebangte Low-Speed-USB
    ohne Weiteres.
    Bootmodus: eine laufende rv003usb-Anwendung geht per HID-Feature-Report 0xAB
    in den Bootloader. Das ist die Konvention dieses Bootloaders, keine USB-Norm;
    ein Ziel, das die Report-ID nicht kennt, quittiert mit einem Stall, und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
    [UsbTarget.cpp, main.cpp]
2026-09-12 HID-Ziele bekommen HidRaw statt Unsupported
    Fuer HID braucht es keinen Host-Treiber: Feature-Reports sind
    Klassen-Steuertransfers auf Endpunkt 0. Genau darueber laufen der Bootmodus
    eines rv003usb-Ziels (Report 0xAB) und das B003-Protokoll. Die Meldung 'kein
    Host-Treiber' war falsch und hat im Web-UI ein Warnabzeichen gezeigt, obwohl
    beides funktioniert.
    Am Geraet: 1209:D003 meldet jetzt driver=hid_raw, und ein POST /api/bootmode
    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
2026-09-12 README: Tabelle der Ziele mit ihren USB-IDs in beiden Modi
    Listet fuer jedes unterstuetzte Ziel die VID:PID der laufenden Anwendung und
    die des Bootloaders, dazu wie die Probe dorthin kommt.
    Mit dem Vorbehalt, der die Tabelle erst ehrlich macht: bei nativem USB vergibt
    die Firmware die IDs der Anwendung, nicht der Chip. Fest liegen nur die
    Bootloader-Werte, weil sie im Boot-ROM stehen oder in einem einmal
    geflashten Bootloader. Genau darum erkennt die Probe Bootloader an der
    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
2026-09-12 Use-after-free bei abgelaufenen Steuertransfers behoben
    Eine Zeitueberschreitung bricht einen USB-Transfer nicht ab. Er kann noch
    fertig werden, und dann ruft der Client-Task den Callback auf. Der
    Fehlerpfad gab aber Semaphor und Transfer sofort frei -- der Callback fasste
    danach beides an.
    Beim CH32V003 ist das der Normalfall statt eines Sonderfalls: das Ziel
    startet auf den Bootmodus-Report hin neu und reisst den Transfer genau dabei
    ab. Der erste Klick hinterliess eine Zeitbombe, der zweite zuendete sie und
    nahm den USB-Stack mit.
    Jetzt haelt ein CtrlWait-Kontext Semaphor und Transfer und ueberlebt den
    Aufrufer. Unter einem Spinlock wird vermerkt, ob der Callback schon da war
    und ob der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
    [UsbTarget.cpp]
2026-09-12 CH32V003: Anwendungscode starten, Scratchpad aushandeln
    /api/reset holt einen CH32V003 aus dem rv003usb-Bootloader zurueck in seine
    Anwendung. Der Bootloader kennt dafuer kein Kommando -- auch das ist eine
    hochgeladene Routine.
    Drei Dinge, die dabei noetig wurden:
    halt_wait_blob zuerst. Der Bootloader springt sonst nach seiner Wartezeit in
    den Anwendungscode und die Sitzung bricht ohne erkennbaren Grund ab.
    Die Scratchpad-Groesse wird ausgehandelt statt geraten, und zwar an der Zahl
    der tatsaechlich zurueckgekommenen Bytes. Nur zu pruefen, ob der Transfer
    durchging, lieferte 6272 statt der echten 128 -- das Start-Magic landete
    hinter dem Pufferende, die Routine lief nie an, und ohne Polli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
    [UsbTarget.cpp, main.cpp]
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2026-09-12 Web-UI: Knopf zum Flashen des CH32V003, Diagnose-Dump raus
    Eigener Abschnitt fuer rv003usb-Ziele mit Dateiauswahl und Fortschritt. Der
    Knopf ist nur im Bootloader freigegeben; laeuft die Anwendung, sagt die Notiz
    warum es nicht geht, statt den Anwender raten zu lassen.
    Der raw-Dump in /api/ch32 faellt weg, er war nur fuer die Inbetriebnahme des
    Protokolls da. Damit entfaellt auch B003Link::lastResponse().
    [main.cpp]
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2026-09-22 Hardware V0.2: Jumpstart-Taster J4 fuer den Schutz-IC
    Der FS312F-G kann beim ersten Anloeten der Zelle stromlos bleiben, bis CS und VSS einmal kurzgeschlossen werden (Datenblatt Rev. 1.2, S. 8). J4 (TS-1088-AR02016) kuerzt das auf einen Tastendruck ab. 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
    Dazu die Bezeichnung praezisiert (FS312F -> FS312F-G) und die Fertigungsunterlagen auf V0.2 gehoben, ODB++ neu dabei.
    [JLC_PCBA_BOM-OpenKNX-DebugProbe(V0.1).xlsx, JLC_PCBA_BOM-OpenKNX-DebugProbe(V0.2).xlsx, OpenKNX-DebugProbe(V0.1).step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]
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2026-10-04 Gehaeuse: dreiteiliger Druck als Fusion-Archiv, Montage im README
    hardware/OpenKNXDebugProbe.f3z kommt dazu. Drei Teile: Deckel, Unterteil und ein optionales Batteriefach ganz unten. Vier M3x20 werden von oben direkt ins Plastik gedreht, Gewindeeinsaetze oder einge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
    Dazu ein Foto des fertigen Aufbaus (docs/case-assembled.jpg), von 4000 auf 1600 px verkleinert -- die EXIF-Daten fallen dabei weg, was bei einem oeffentlichen Repo erwuenscht ist.
    Nebenbei: hardware/README.md zeigte noch auf das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
    [OpenKNXDebugProbe.f3z]
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
